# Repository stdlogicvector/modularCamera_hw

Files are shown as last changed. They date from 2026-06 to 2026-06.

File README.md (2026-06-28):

# ModularCamera Hardware

This repository contains the schematics and layouts for the PCBs that make up the ModularCamera system.
They are divided into three categories:

## Interface

USB3 Interface PCB

This is the layer that connects the modularCamera to a PC. At the moment the following interfaces are implemented:

- USB3: Using a Cypress FX3 chip to communicate with a PC via an USB-C cable
- GigE: Providing a Gigabit Ethernet connection with an optional PoE add-on board

The boards are fully self contained, bringing all the power supplies and configuration memories they need.
To connect to the next layer, a 70 pin connector transports up to 42 signals plus 22x GND and 6x 5V.

## Processing

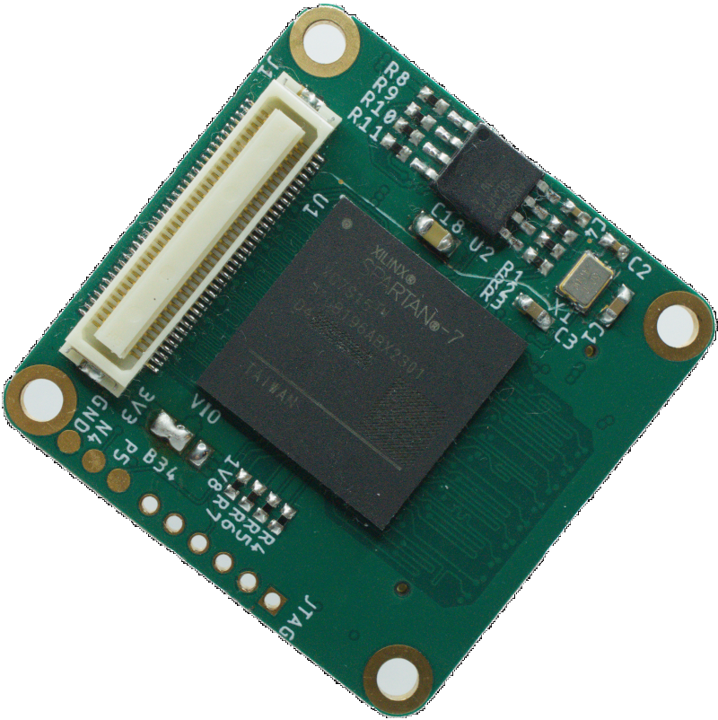
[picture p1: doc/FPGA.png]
Spartan7 Processing PCB


The central layer of the stack does everything from controlling the sensors,  processing the data and formatting it for output. Right now, there are two FPGA boards, but microcontrollers would also be possible.

- Spartan7: A XC72S15 FPGA from Xilinx
- Spartan6: A XC6SLX16 FPGA from Xilinx

Besides the FPGA, the boards have several power supplies for the FPGA, a configuration memory and a clock source. The connector to the next layer has  up to 42 signals plus 22x GND and 6x 5V.

## Sensor

EV76C560 Sensor PCB

This is were the modularity shines. With the high flexibility of the FPGAs, almost all sensors can be interfaced with minimal additional components.
The focus lies on image sensors, but the system isn't limited to processing pixels:

- AISC110C: A small image sensor with a resolution of 80x120 px but a maximum framerate of 40000fps! Configured via SPI.
- ADV7182: An SDTV Video Decoder that accepts lots of analog video formats. Configured via I2C.
- HallArray: An 8x8 array of hall sensors interfaced with an analog matrix. Makes magnetic fields visible.
- MT9P031: A 5MP B/W CMOS image sensor with 14fps. Configured via I2C.
- EV76C560: A 1.3MP B/W CMOS image sensor with global shutter and 60ps. Configured via SPI.
- LinearCCD: A board for interfacing several linear CCD arrays. Provides a driver chip for clocking&control signals, a step-up for power supply and up to 3 12bit 5MSPS ADCs. The sensors are connected via an additional board to accomodate for different pinouts.
- NOIP1SN300: A 1.3MP B/W CMOS image sensor with global shutter and up to 815fps. Configured via SPI.
- IBIS5-B-1300: A 1.3MP B/W CMOS image sensor with global shutter and 27fps. Configured via SPI. (WIP)
- Cameralink: A CameraLink-Base Interface with optional PoCL. Makes the modularCamera into a CameraLink framegrabber. (WIP)
- Microphone Array: A board containing three I2S MEMS microphones. (WIP)

The boards should provide everything necessary to operate the sensor. The connector to the lower layer provides 5V and the control/data interface.

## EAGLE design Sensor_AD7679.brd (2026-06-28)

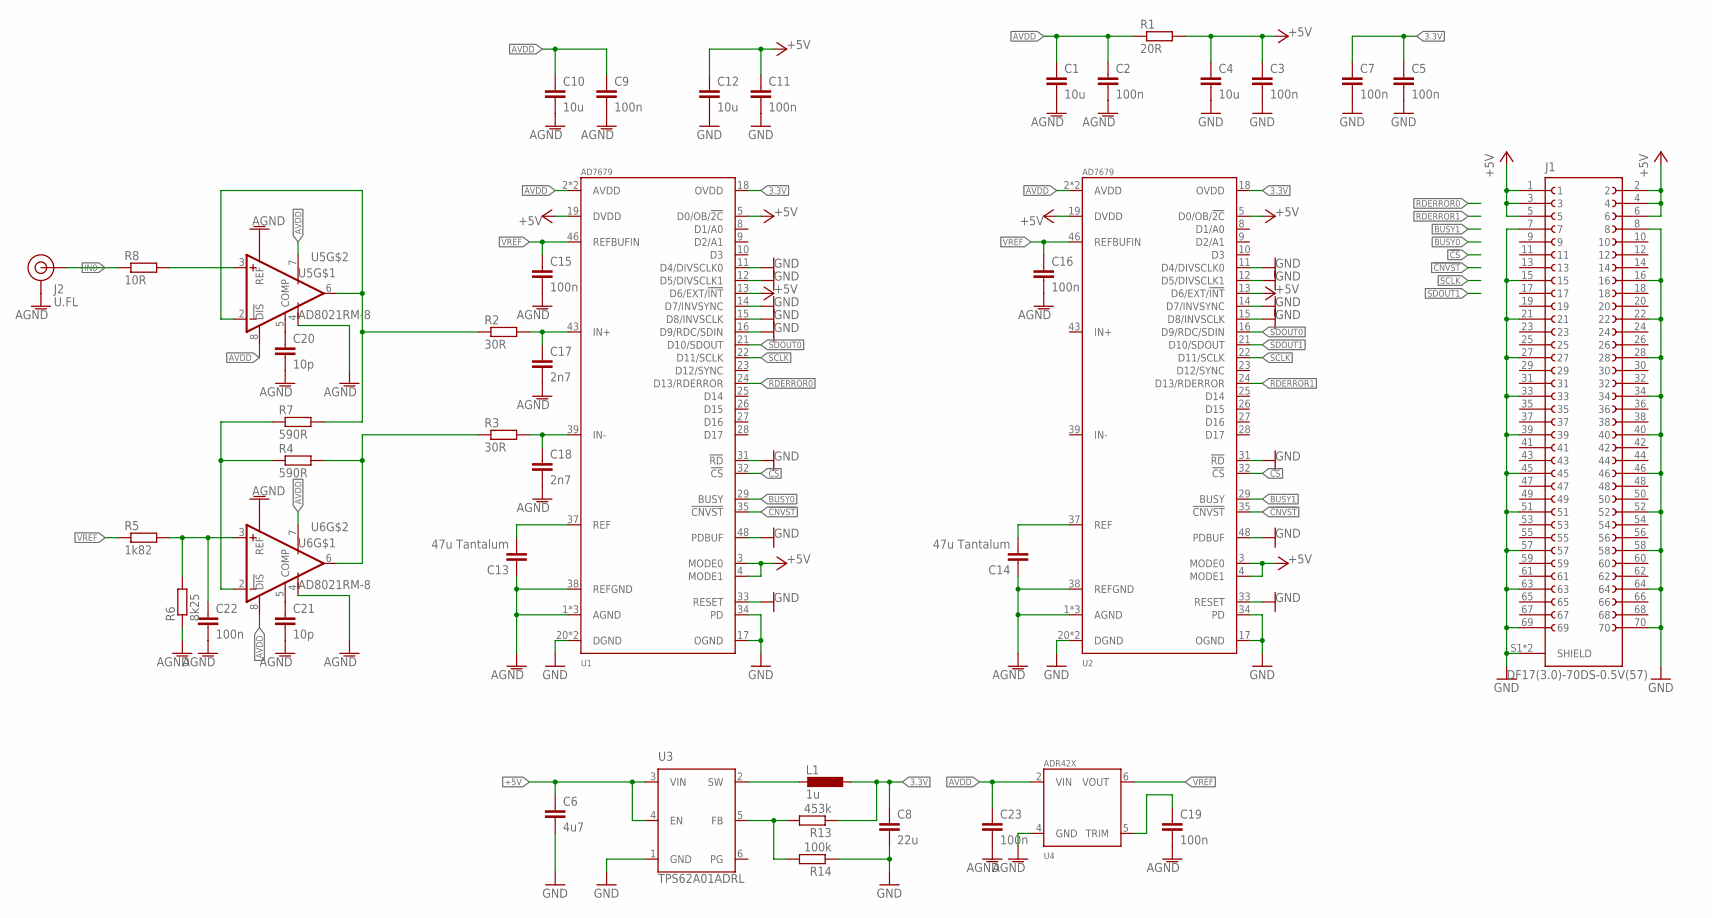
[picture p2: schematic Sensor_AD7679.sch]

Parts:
C1, C4, C10, C12: 10u; C0603
C2, C3, C5, C7, C9, C11, C15, C16, C19, C22, C23: 100n; C0402; LCSC C1525
C6: 4u7; C0603; LCSC C19666
C8: 22u; C0603; LCSC C109448
C13, C14: 47u Tantalum; C1206; DIGIKEY 478-TCA0J476M8R-02CT-ND
C17, C18: 2n7; C0402
C20, C21: 10p; C0402
J1: DF17(3.0)-70DS-0.5V(57)
J2: U.FL; DIGIKEY 26-U.FL-R-SMT-1(01)-ND
L1: 1u; L1008; MPN LQM2HPN1R0MG0L; DIGIKEY 490-5112-1-ND
R1: 20R; R0402
R2, R3: 30R; R0402
R4, R7: 590R; R0402
R5: 1k82; R0402
R6: 8k25; R0402
R8: 10R; R0402
R13: 453k; R0402; LCSC C137978
R14: 100k; R0402; DIGIKEY RMCF0402FT100KCT-ND
U1, U2: AD7679; LQFP48
U3: TPS62A01ADRL; SOTFL50P160X60-6N; DIGIKEY 296-TPS62A01ADRLRCT-ND
U4: ADR42X; MSOP08
U5, U6: AD8021RM-8; MSOP08

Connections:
3.3V: C5.1, C7.1, C8.1, L1.1, R13.1, U1.18 (OVDD), U2.18 (OVDD)
!CNVST: U1.35 (!CNVST), U2.35 (!CNVST)
!CS: U1.32 (!CS), U2.32 (!CS)
+5V: C3.1, C4.1, C6.1, C11.1, C12.1, J1.1, J1.2, J1.3, J1.4, J1.5, J1.6, R1.2, U1.3 (MODE0), U1.4 (MODE1), U1.5 (D0/OB/!2C), U1.19 (DVDD), U2.3 (MODE0), U2.4 (MODE1), U2.5 (D0/OB/!2C), U2.13 (D6/EXT/!INT), U2.19 (DVDD), U3.3 (VIN), U3.4 (EN)
AGND: C1.2, C2.2, C9.2, C10.2, C13.1, C14.1, C15.2, C16.2, C17.2, C18.2, C19.2, C20.2, C21.2, C22.2, C23.2, J2.1 (GND), J2.2 (GND), R6.1, U1.1 (AGND), U1.36 (AGND), U1.38 (REFGND), U1.44 (AGND), U2.1 (AGND), U2.36 (AGND), U2.38 (REFGND), U2.44 (AGND), U4.4 (GND), U5.1 (REF), U5.4 (V-), U6.1 (REF), U6.4 (V-)
AVDD: C1.1, C2.1, C9.1, C10.1, C23.1, R1.1, U1.2 (AVDD), U1.47 (AVDD), U2.2 (AVDD), U2.47 (AVDD), U4.2 (VIN), U5.7 (V+), U5.8 (!DIS), U6.7 (V+), U6.8 (!DIS)
BUSY0: U1.29 (BUSY)
BUSY1: U2.29 (BUSY)
GND: C3.2, C4.2, C5.2, C6.2, C7.2, C8.2, C11.2, C12.2, J1.7, J1.8, J1.15, J1.16, J1.21, J1.22, J1.27, J1.28, J1.33, J1.34, J1.39, J1.40, J1.45, J1.46, J1.51, J1.52, J1.57, J1.58, J1.63, J1.64, J1.69, J1.70, J1.S1 (SHIELD), J1.S2 (SHIELD), R14.1, U1.11 (D4/DIVSCLK0), U1.12 (D5/DIVSCLK1), U1.14 (D7/INVSYNC), U1.17 (OGND), U1.20 (DGND), U1.30 (DGND), U1.31 (!RD), U1.33 (RESET), U1.34 (PD), U1.48 (PDBUF), U2.11 (D4/DIVSCLK0), U2.12 (D5/DIVSCLK1), U2.14 (D7/INVSYNC), U2.15 (D8/INVSCLK), U2.17 (OGND), U2.20 (DGND), U2.30 (DGND), U2.31 (!RD), U2.33 (RESET), U2.34 (PD), U2.48 (PDBUF), U3.1 (GND)
IN0: J2.FEED (SIGNAL), R8.1
unnamed: C13.2, U1.37 (REF)
unnamed: C14.2, U2.37 (REF)
unnamed: U1.15 (D8/INVSCLK), U1.16 (D9/RDC/SDIN)
unnamed: R2.1, R7.2, U5.2 (-IN), U5.6 (OUT)
unnamed: C20.1, U5.5 (COMP)
unnamed: C17.1, R2.2, U1.43 (IN+)
unnamed: C18.1, R3.2, U1.39 (IN-)
unnamed: C19.1, U4.5 (TRIM)
unnamed: R4.1, R7.1, U6.2 (-IN)
unnamed: C21.1, U6.5 (COMP)
unnamed: R3.1, R4.2, U6.6 (OUT)
unnamed: C22.1, R5.2, R6.2, U6.3 (+IN)
unnamed: R8.2, U5.3 (+IN)
unnamed: R13.2, R14.2, U3.5 (FB)
unnamed: L1.2, U3.2 (SW)
RDERROR0: U1.24 (D13/RDERROR)
RDERROR1: U2.24 (D13/RDERROR)
SCLK: U1.22 (D11/SCLK), U2.22 (D11/SCLK)
SDOUT0: U1.21 (D10/SDOUT), U2.16 (D9/RDC/SDIN)
SDOUT1: U2.21 (D10/SDOUT)
VREF: C15.1, C16.1, R5.1, U1.46 (REFBUFIN), U2.46 (REFBUFIN), U4.6 (VOUT)

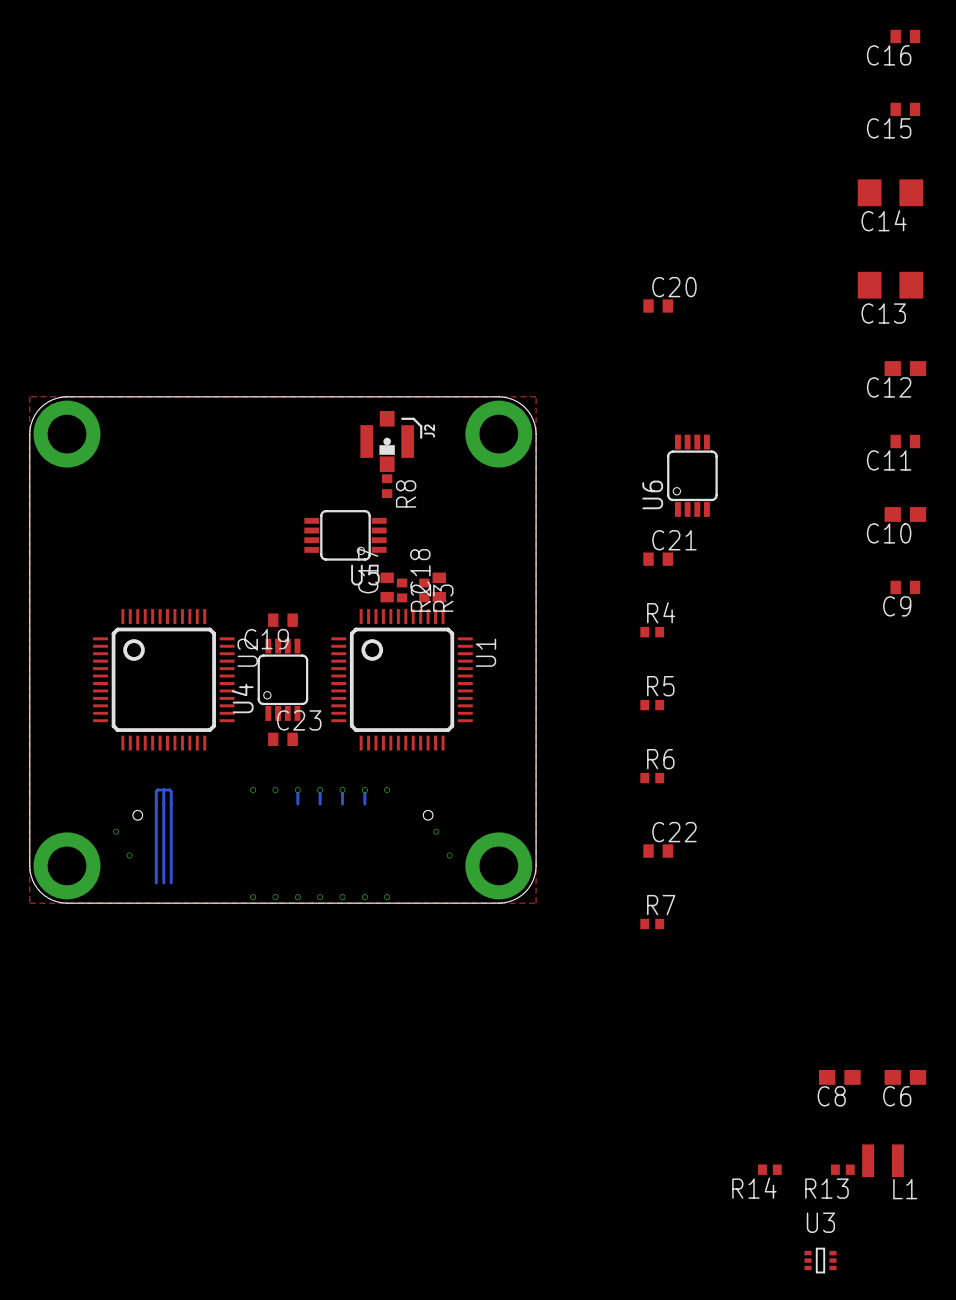
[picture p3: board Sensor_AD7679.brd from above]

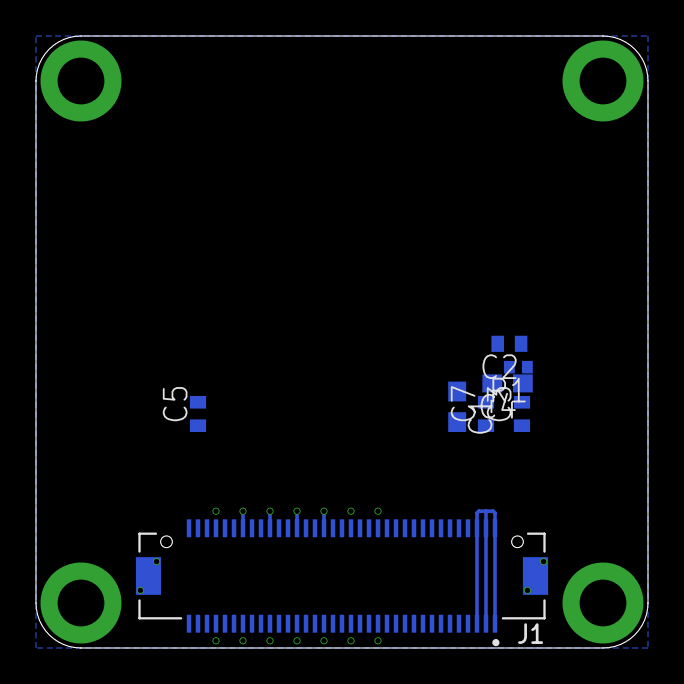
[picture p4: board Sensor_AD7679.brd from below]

Board: 4 copper layers, 34.0 x 34.0 mm, 42 parts (8 on the bottom side), 26 nets.

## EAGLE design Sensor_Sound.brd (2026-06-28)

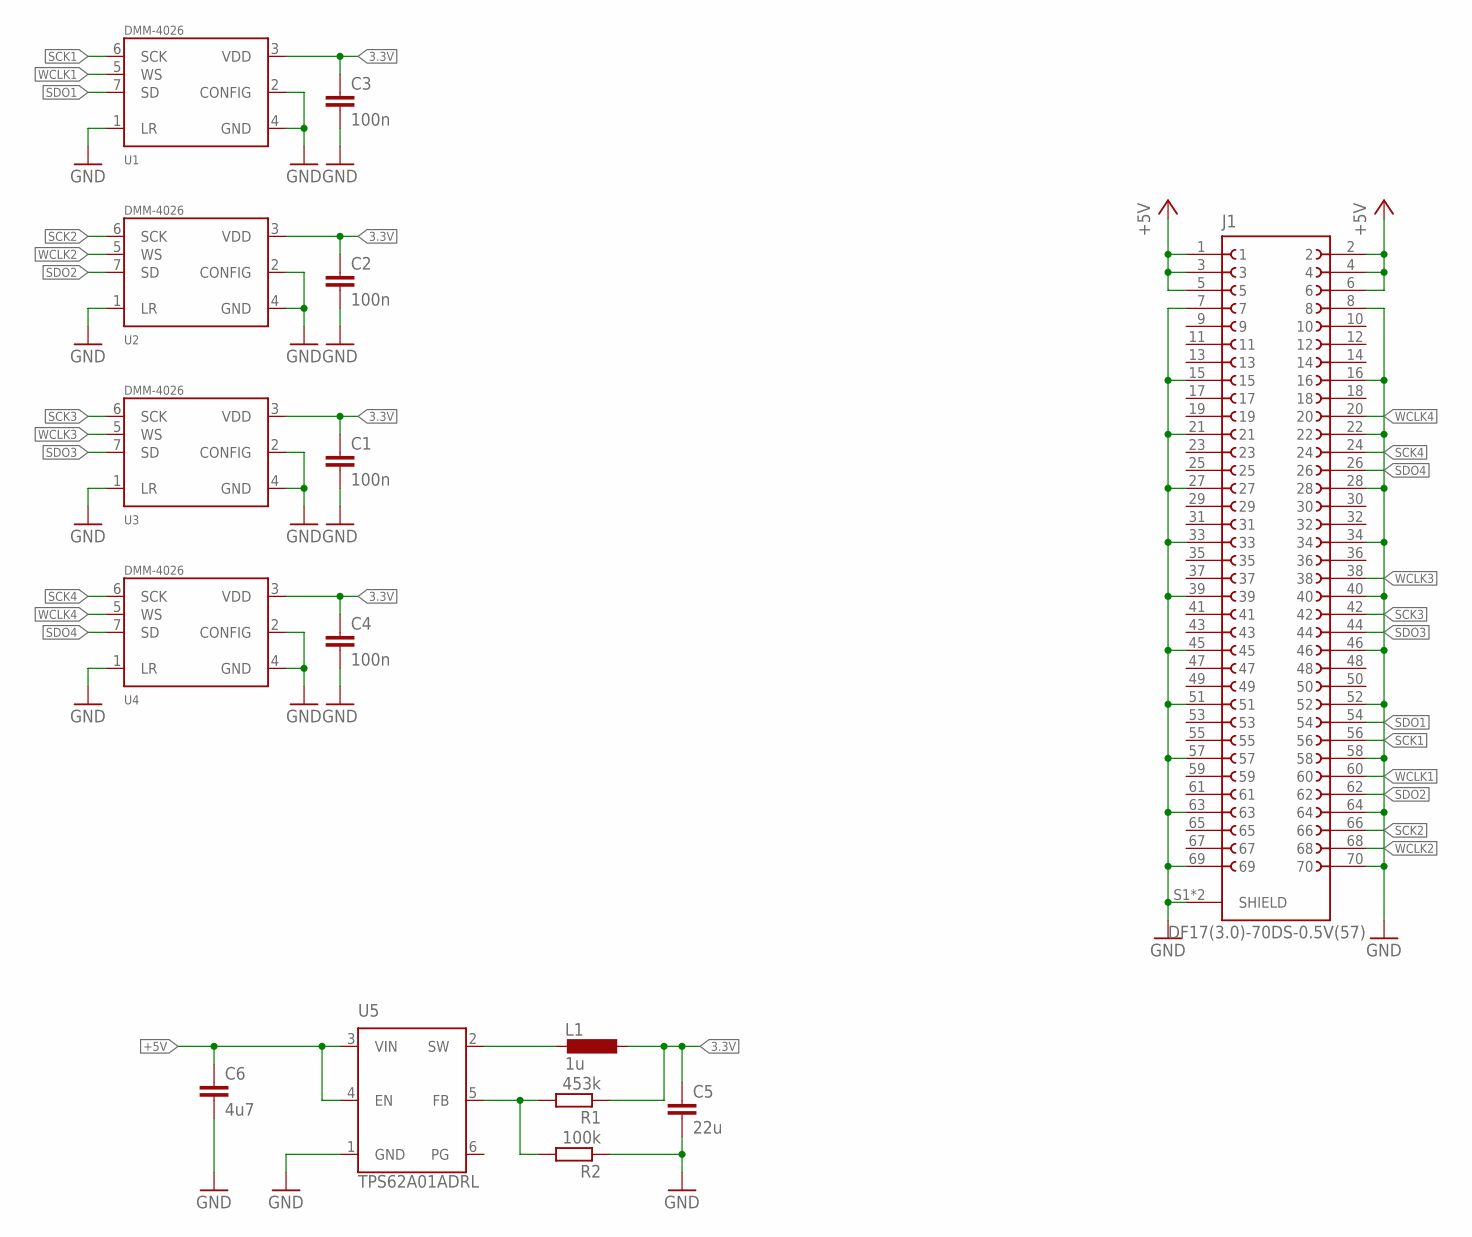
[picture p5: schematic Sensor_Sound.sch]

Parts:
C1, C2, C3, C4: 100n; C0402; LCSC C1525
C5: 22u; C0603; LCSC C109448
C6: 4u7; C0603; LCSC C19666
J1: DF17(3.0)-70DS-0.5V(57)
L1: 1u; L1008; MPN LQM2HPN1R0MG0L; DIGIKEY 490-5112-1-ND
R1: 453k; R0402; LCSC C137978
R2: 100k; R0402; DIGIKEY RMCF0402FT100KCT-ND
U1, U2, U3, U4: DMM-4026
U5: TPS62A01ADRL; SOTFL50P160X60-6N; DIGIKEY 296-TPS62A01ADRLRCT-ND

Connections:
3.3V: C1.1, C2.1, C3.1, C4.1, C5.1, L1.1, R1.1, U1.3 (VDD), U2.3 (VDD), U3.3 (VDD), U4.3 (VDD)
+5V: C6.1, J1.1, J1.2, J1.3, J1.4, J1.5, J1.6, U5.3 (VIN), U5.4 (EN)
GND: C1.2, C2.2, C3.2, C4.2, C5.2, C6.2, J1.7, J1.8, J1.15, J1.16, J1.21, J1.22, J1.27, J1.28, J1.33, J1.34, J1.39, J1.40, J1.45, J1.46, J1.51, J1.52, J1.57, J1.58, J1.63, J1.64, J1.69, J1.70, J1.S1 (SHIELD), J1.S2 (SHIELD), R2.1, U1.1 (LR), U1.2 (CONFIG), U1.4 (GND), U2.1 (LR), U2.2 (CONFIG), U2.4 (GND), U3.1 (LR), U3.2 (CONFIG), U3.4 (GND), U4.1 (LR), U4.2 (CONFIG), U4.4 (GND), U5.1 (GND)
unnamed: R1.2, R2.2, U5.5 (FB)
unnamed: L1.2, U5.2 (SW)
SCK1: J1.56, U1.6 (SCK)
SCK2: J1.66, U2.6 (SCK)
SCK3: J1.42, U3.6 (SCK)
SCK4: J1.24, U4.6 (SCK)
SDO1: J1.54, U1.7 (SD)
SDO2: J1.62, U2.7 (SD)
SDO3: J1.44, U3.7 (SD)
SDO4: J1.26, U4.7 (SD)
WCLK1: J1.60, U1.5 (WS)
WCLK2: J1.68, U2.5 (WS)
WCLK3: J1.38, U3.5 (WS)
WCLK4: J1.20, U4.5 (WS)

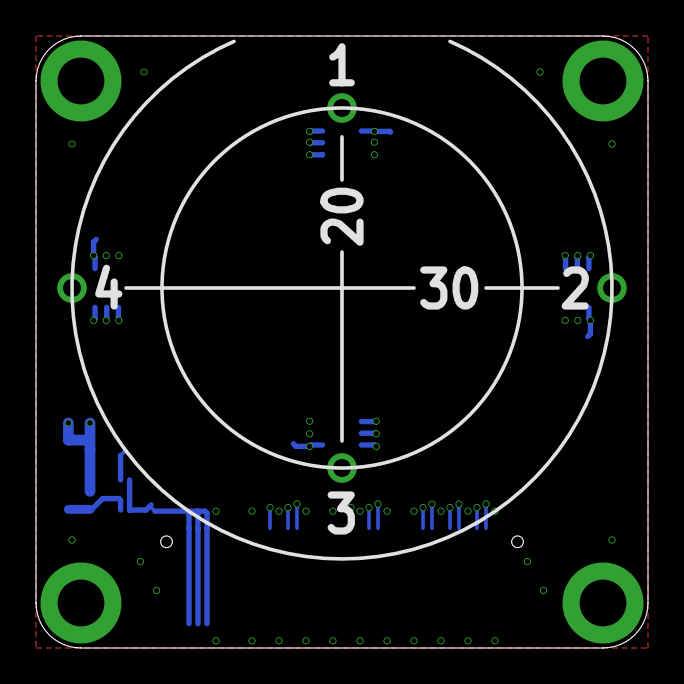
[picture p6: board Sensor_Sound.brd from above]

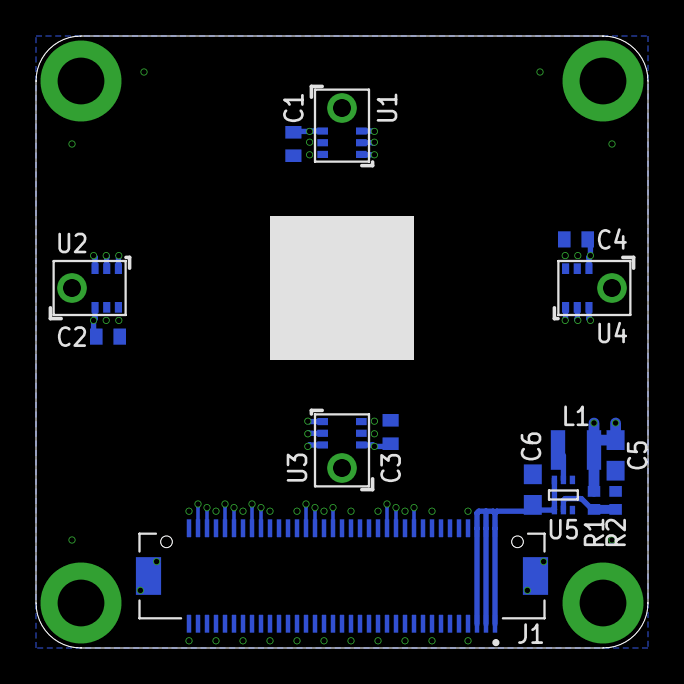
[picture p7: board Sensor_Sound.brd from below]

Board: 4 copper layers, 34.0 x 34.0 mm, 15 parts (15 on the bottom side), 17 nets.

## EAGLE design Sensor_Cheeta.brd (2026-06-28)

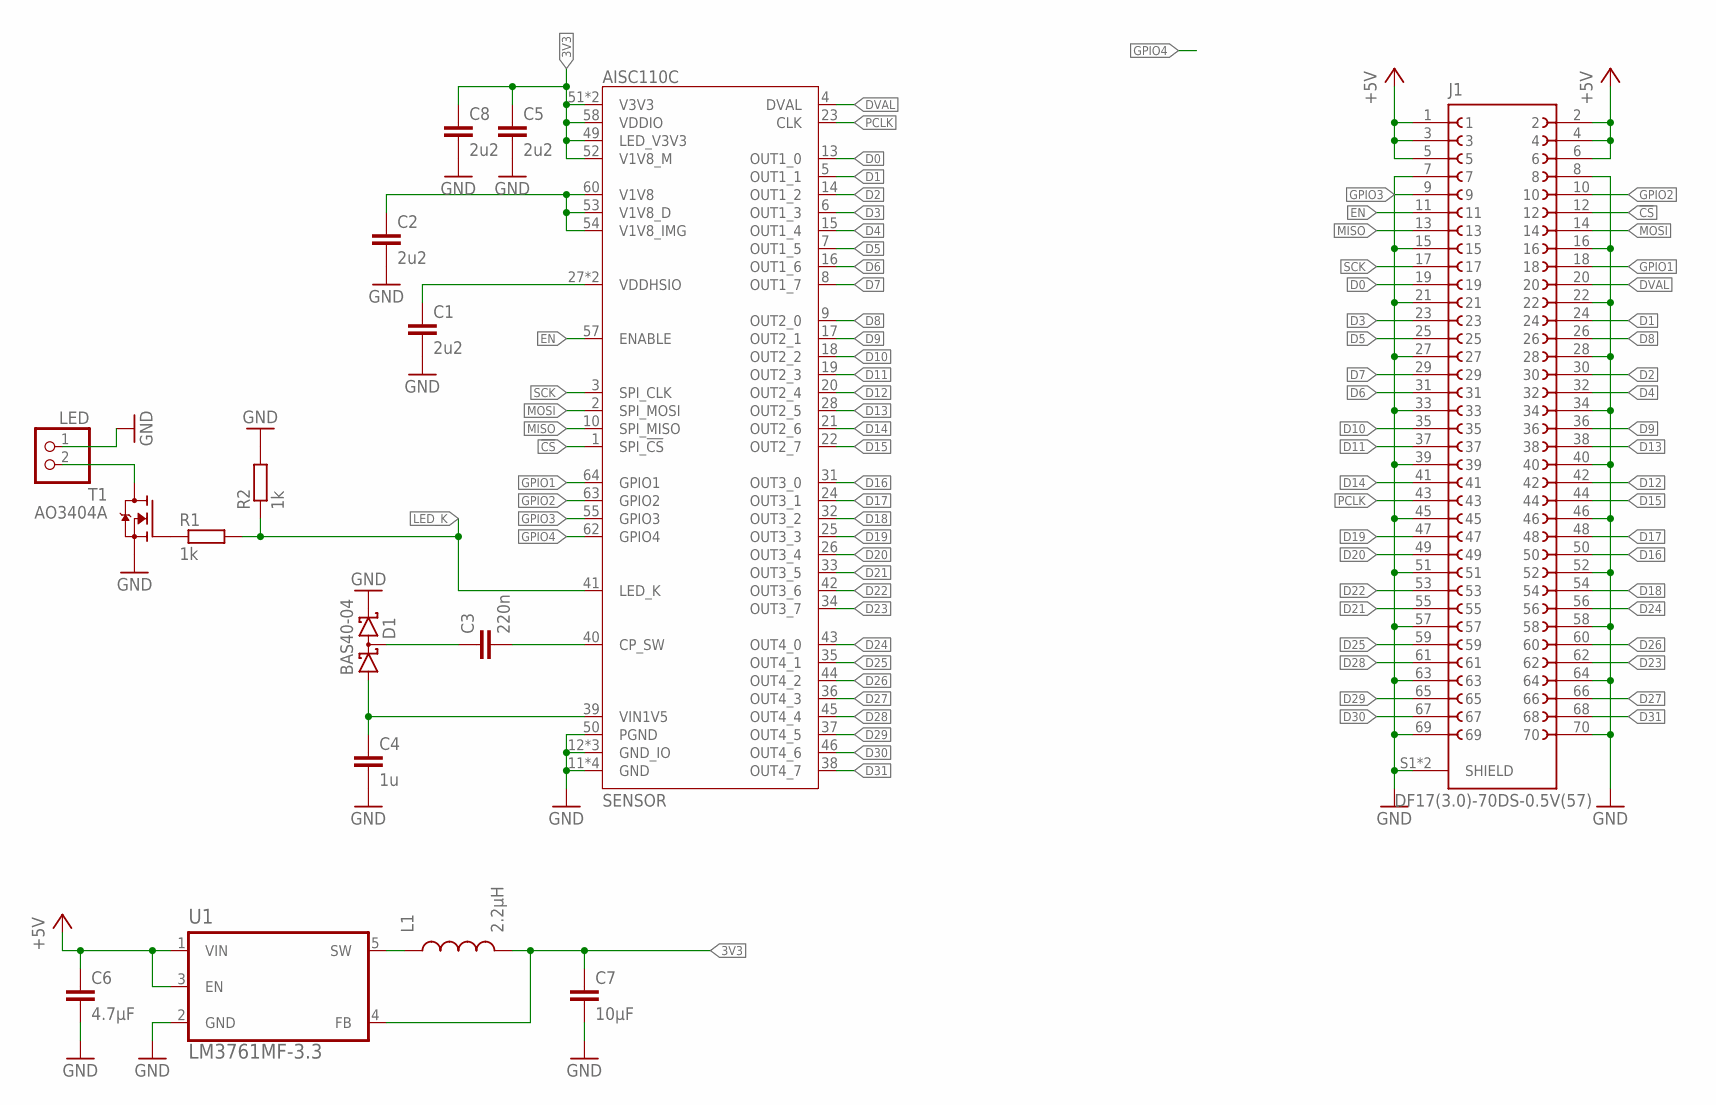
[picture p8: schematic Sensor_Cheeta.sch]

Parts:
C1, C2, C5, C8: 2u2; C0603
C3: 220n; C0603
C4: 1u; C0603
C6: 4.7µF; C0603
C7: 10µF; C0603
D1: BAS40-04; SOT23
J1: DF17(3.0)-70DS-0.5V(57)
L1: 2.2µH; SO3314; FARNELL 2457514
LED: PINHD-1X2; 1X02
R1, R2: 1k; R0603; LCSC C11702
SENSOR: AISC110C; 64_LD_OLGA
T1: AO3404A; SOT23; LCSC C30010
U1: LM3761MF-3.3; SOT95P284X122-5N

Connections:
3V3: C5.1, C7.1, C8.1, L1.2, SENSOR.49 (LED_V3V3), SENSOR.51 (V3V3), SENSOR.52 (V1V8_M), SENSOR.58 (VDDIO), SENSOR.59 (V3V3), U1.4 (FB)
!CS: J1.12, SENSOR.1 (SPI_!CS)
+5V: C6.1, J1.1, J1.2, J1.3, J1.4, J1.5, J1.6, U1.1 (VIN), U1.3 (EN)
D0: J1.19, SENSOR.13 (OUT1_0)
D1: J1.24, SENSOR.5 (OUT1_1)
D2: J1.30, SENSOR.14 (OUT1_2)
D3: J1.23, SENSOR.6 (OUT1_3)
D4: J1.32, SENSOR.15 (OUT1_4)
D5: J1.25, SENSOR.7 (OUT1_5)
D6: J1.31, SENSOR.16 (OUT1_6)
D7: J1.29, SENSOR.8 (OUT1_7)
D8: J1.26, SENSOR.9 (OUT2_0)
D9: J1.36, SENSOR.17 (OUT2_1)
D10: J1.35, SENSOR.18 (OUT2_2)
D11: J1.37, SENSOR.19 (OUT2_3)
D12: J1.42, SENSOR.20 (OUT2_4)
D13: J1.38, SENSOR.28 (OUT2_5)
D14: J1.41, SENSOR.21 (OUT2_6)
D15: J1.44, SENSOR.22 (OUT2_7)
D16: J1.50, SENSOR.31 (OUT3_0)
D17: J1.48, SENSOR.24 (OUT3_1)
D18: J1.54, SENSOR.32 (OUT3_2)
D19: J1.47, SENSOR.25 (OUT3_3)
D20: J1.49, SENSOR.26 (OUT3_4)
D21: J1.55, SENSOR.33 (OUT3_5)
D22: J1.53, SENSOR.42 (OUT3_6)
D23: J1.62, SENSOR.34 (OUT3_7)
D24: J1.56, SENSOR.43 (OUT4_0)
D25: J1.59, SENSOR.35 (OUT4_1)
D26: J1.60, SENSOR.44 (OUT4_2)
D27: J1.66, SENSOR.36 (OUT4_3)
D28: J1.61, SENSOR.45 (OUT4_4)
D29: J1.65, SENSOR.37 (OUT4_5)
D30: J1.67, SENSOR.46 (OUT4_6)
D31: J1.68, SENSOR.38 (OUT4_7)
DVAL: J1.20, SENSOR.4 (DVAL)
EN: J1.11, SENSOR.57 (ENABLE)
GND: C1.2, C2.2, C4.2, C5.2, C6.2, C7.2, C8.2, D1.2 (C2), J1.7, J1.8, J1.15, J1.16, J1.21, J1.22, J1.27, J1.28, J1.33, J1.34, J1.39, J1.40, J1.45, J1.46, J1.51, J1.52, J1.57, J1.58, J1.63, J1.64, J1.69, J1.70, J1.S1 (SHIELD), J1.S2 (SHIELD), LED.1, R2.2, SENSOR.11 (GND), SENSOR.12 (GND_IO), SENSOR.30 (GND_IO), SENSOR.47 (GND_IO), SENSOR.48 (GND), SENSOR.50 (PGND), SENSOR.56 (GND), SENSOR.61 (GND), T1.2 (S), U1.2 (GND)
GPIO1: J1.18, SENSOR.64 (GPIO1)
GPIO2: J1.10, SENSOR.63 (GPIO2)
GPIO3: J1.9, SENSOR.55 (GPIO3)
GPIO4: SENSOR.62 (GPIO4)
LED_K: R1.2, R2.1, SENSOR.41 (LED_K)
MISO: J1.13, SENSOR.10 (SPI_MISO)
MOSI: J1.14, SENSOR.2 (SPI_MOSI)
unnamed: C3.2, SENSOR.40 (CP_SW)
unnamed: C4.1, D1.1 (A1), SENSOR.39 (VIN1V5)
unnamed: C3.1, D1.3 (C1A2)
unnamed: LED.2, T1.3 (D)
unnamed: L1.1, U1.5 (SW)
unnamed: C2.1, SENSOR.53 (V1V8_D), SENSOR.54 (V1V8_IMG), SENSOR.60 (V1V8)
unnamed: C1.1, SENSOR.27 (VDDHSIO), SENSOR.29 (VDDHSIO)
unnamed: R1.1, T1.1 (G)
PCLK: J1.43, SENSOR.23 (CLK)
SCK: J1.17, SENSOR.3 (SPI_CLK)

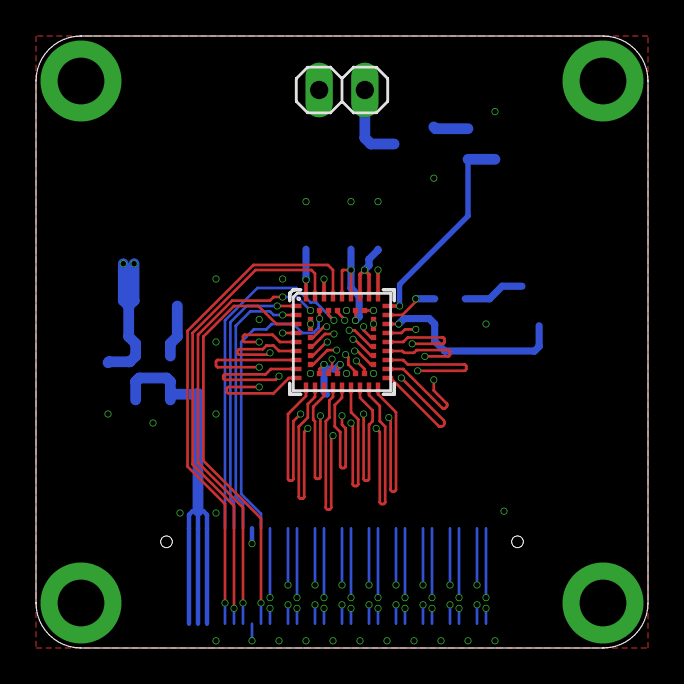
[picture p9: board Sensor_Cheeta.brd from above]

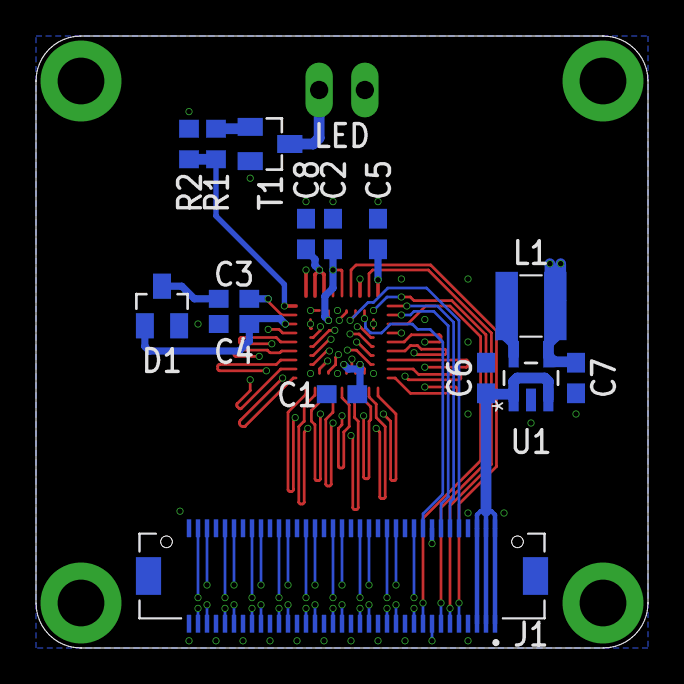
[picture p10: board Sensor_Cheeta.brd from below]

Board: 4 copper layers, 34.0 x 34.0 mm, 17 parts (15 on the bottom side), 54 nets.

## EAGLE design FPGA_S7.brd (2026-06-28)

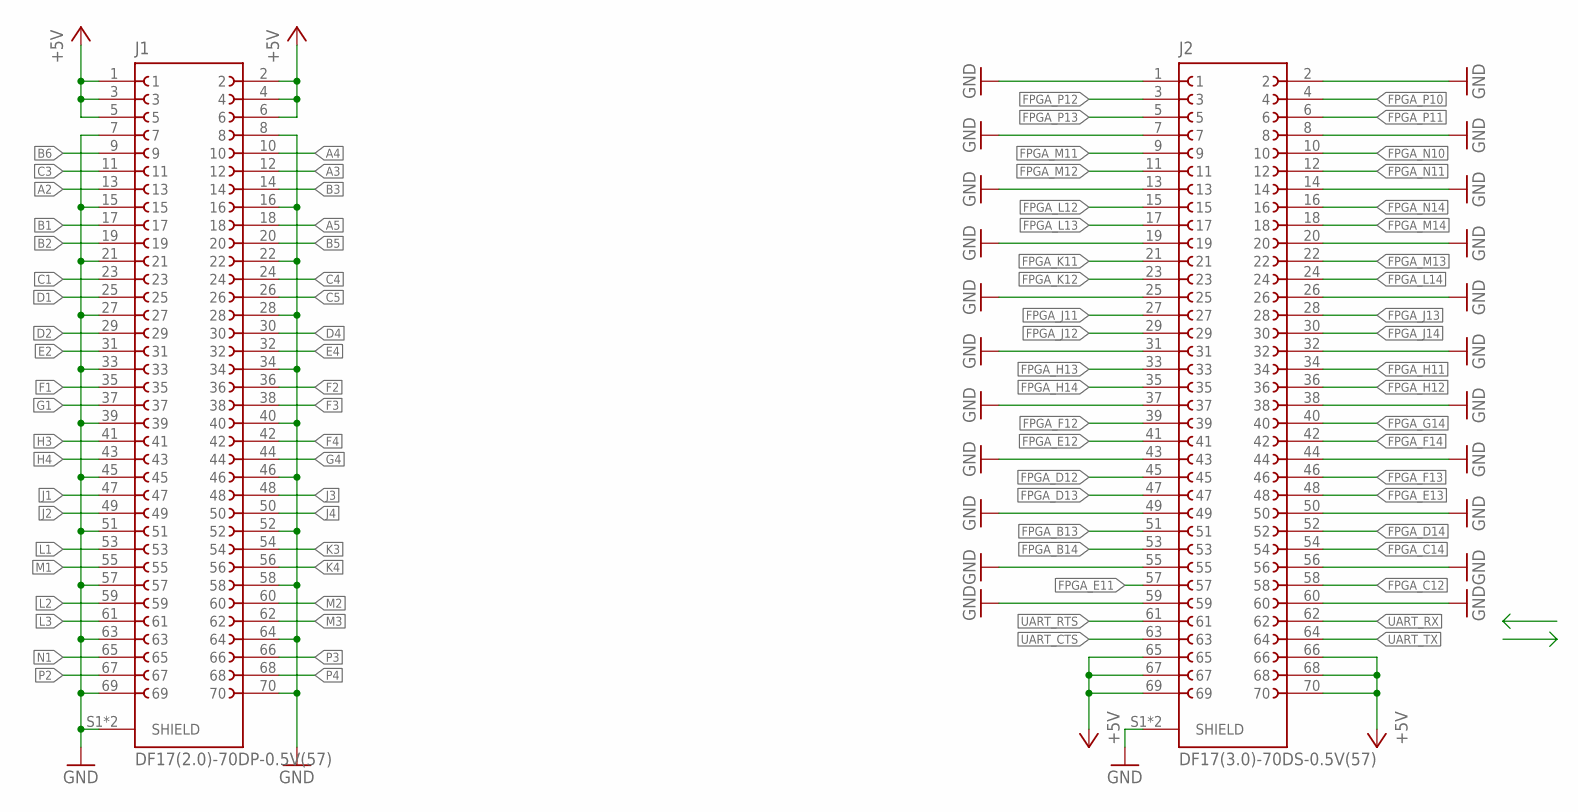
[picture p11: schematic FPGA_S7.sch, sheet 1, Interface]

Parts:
J1: DF17(2.0)-70DP-0.5V(57); DIGIKEY H11133CT-ND
J2: DF17(3.0)-70DS-0.5V(57); DIGIKEY H11112CT-ND

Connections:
+5V: J1.1, J1.2, J1.3, J1.4, J1.5, J1.6, J2.65, J2.66, J2.67, J2.68, J2.69, J2.70; also elsewhere on the board
A2: J1.13; also elsewhere on the board
A3: J1.12; also elsewhere on the board
A4: J1.10; also elsewhere on the board
A5: J1.18; also elsewhere on the board
B1: J1.17; also elsewhere on the board
B2: J1.19; also elsewhere on the board
B3: J1.14; also elsewhere on the board
B5: J1.20; also elsewhere on the board
B6: J1.9; also elsewhere on the board
C1: J1.23; also elsewhere on the board
C3: J1.11; also elsewhere on the board
C4: J1.24; also elsewhere on the board
C5: J1.26; also elsewhere on the board
D1: J1.25; also elsewhere on the board
D2: J1.29; also elsewhere on the board
D4: J1.30; also elsewhere on the board
E2: J1.31; also elsewhere on the board
E4: J1.32; also elsewhere on the board
F1: J1.35; also elsewhere on the board
F2: J1.36; also elsewhere on the board
F3: J1.38; also elsewhere on the board
F4: J1.42; also elsewhere on the board
FPGA_B13: J2.51; also elsewhere on the board
FPGA_B14: J2.53; also elsewhere on the board
FPGA_C12: J2.58; also elsewhere on the board
FPGA_C14: J2.54; also elsewhere on the board
FPGA_D12: J2.45; also elsewhere on the board
FPGA_D13: J2.47; also elsewhere on the board
FPGA_D14: J2.52; also elsewhere on the board
FPGA_E11: J2.57; also elsewhere on the board
FPGA_E12: J2.41; also elsewhere on the board
FPGA_E13: J2.48; also elsewhere on the board
FPGA_F12: J2.39; also elsewhere on the board
FPGA_F13: J2.46; also elsewhere on the board
FPGA_F14: J2.42; also elsewhere on the board
FPGA_G14: J2.40; also elsewhere on the board
FPGA_H11: J2.34; also elsewhere on the board
FPGA_H12: J2.36; also elsewhere on the board
FPGA_H13: J2.33; also elsewhere on the board
FPGA_H14: J2.35; also elsewhere on the board
FPGA_J11: J2.27; also elsewhere on the board
FPGA_J12: J2.29; also elsewhere on the board
FPGA_J13: J2.28; also elsewhere on the board
FPGA_J14: J2.30; also elsewhere on the board
FPGA_K11: J2.21; also elsewhere on the board
FPGA_K12: J2.23; also elsewhere on the board
FPGA_L12: J2.15; also elsewhere on the board
FPGA_L13: J2.17; also elsewhere on the board
FPGA_L14: J2.24; also elsewhere on the board
FPGA_M11: J2.9; also elsewhere on the board
FPGA_M12: J2.11; also elsewhere on the board
FPGA_M13: J2.22; also elsewhere on the board
FPGA_M14: J2.18; also elsewhere on the board
FPGA_N10: J2.10; also elsewhere on the board
FPGA_N11: J2.12; also elsewhere on the board
FPGA_N14: J2.16; also elsewhere on the board
FPGA_P10: J2.4; also elsewhere on the board
FPGA_P11: J2.6; also elsewhere on the board
FPGA_P12: J2.3; also elsewhere on the board
FPGA_P13: J2.5; also elsewhere on the board
G1: J1.37; also elsewhere on the board
G4: J1.44; also elsewhere on the board
GND: J1.7, J1.8, J1.15, J1.16, J1.21, J1.22, J1.27, J1.28, J1.33, J1.34, J1.39, J1.40, J1.45, J1.46, J1.51, J1.52, J1.57, J1.58, J1.63, J1.64, J1.69, J1.70, J1.S1 (SHIELD), J1.S2 (SHIELD), J2.1, J2.2, J2.7, J2.8, J2.13, J2.14, J2.19, J2.20, J2.25, J2.26, J2.31, J2.32, J2.37, J2.38, J2.43, J2.44, J2.49, J2.50, J2.55, J2.56, J2.59, J2.60, J2.S1 (SHIELD), J2.S2 (SHIELD); also elsewhere on the board
H3: J1.41; also elsewhere on the board
H4: J1.43; also elsewhere on the board
J1: J1.47; also elsewhere on the board
J2: J1.49; also elsewhere on the board
J3: J1.48; also elsewhere on the board
J4: J1.50; also elsewhere on the board
K3: J1.54; also elsewhere on the board
K4: J1.56; also elsewhere on the board
L1: J1.53; also elsewhere on the board
L2: J1.59; also elsewhere on the board
L3: J1.61; also elsewhere on the board
M1: J1.55; also elsewhere on the board
M2: J1.60; also elsewhere on the board
M3: J1.62; also elsewhere on the board
N1: J1.65; also elsewhere on the board
P2: J1.67; also elsewhere on the board
P3: J1.66; also elsewhere on the board
P4: J1.68; also elsewhere on the board
UART_CTS: J2.63; also elsewhere on the board
UART_RTS: J2.61; also elsewhere on the board
UART_RX: J2.62; also elsewhere on the board
UART_TX: J2.64; also elsewhere on the board

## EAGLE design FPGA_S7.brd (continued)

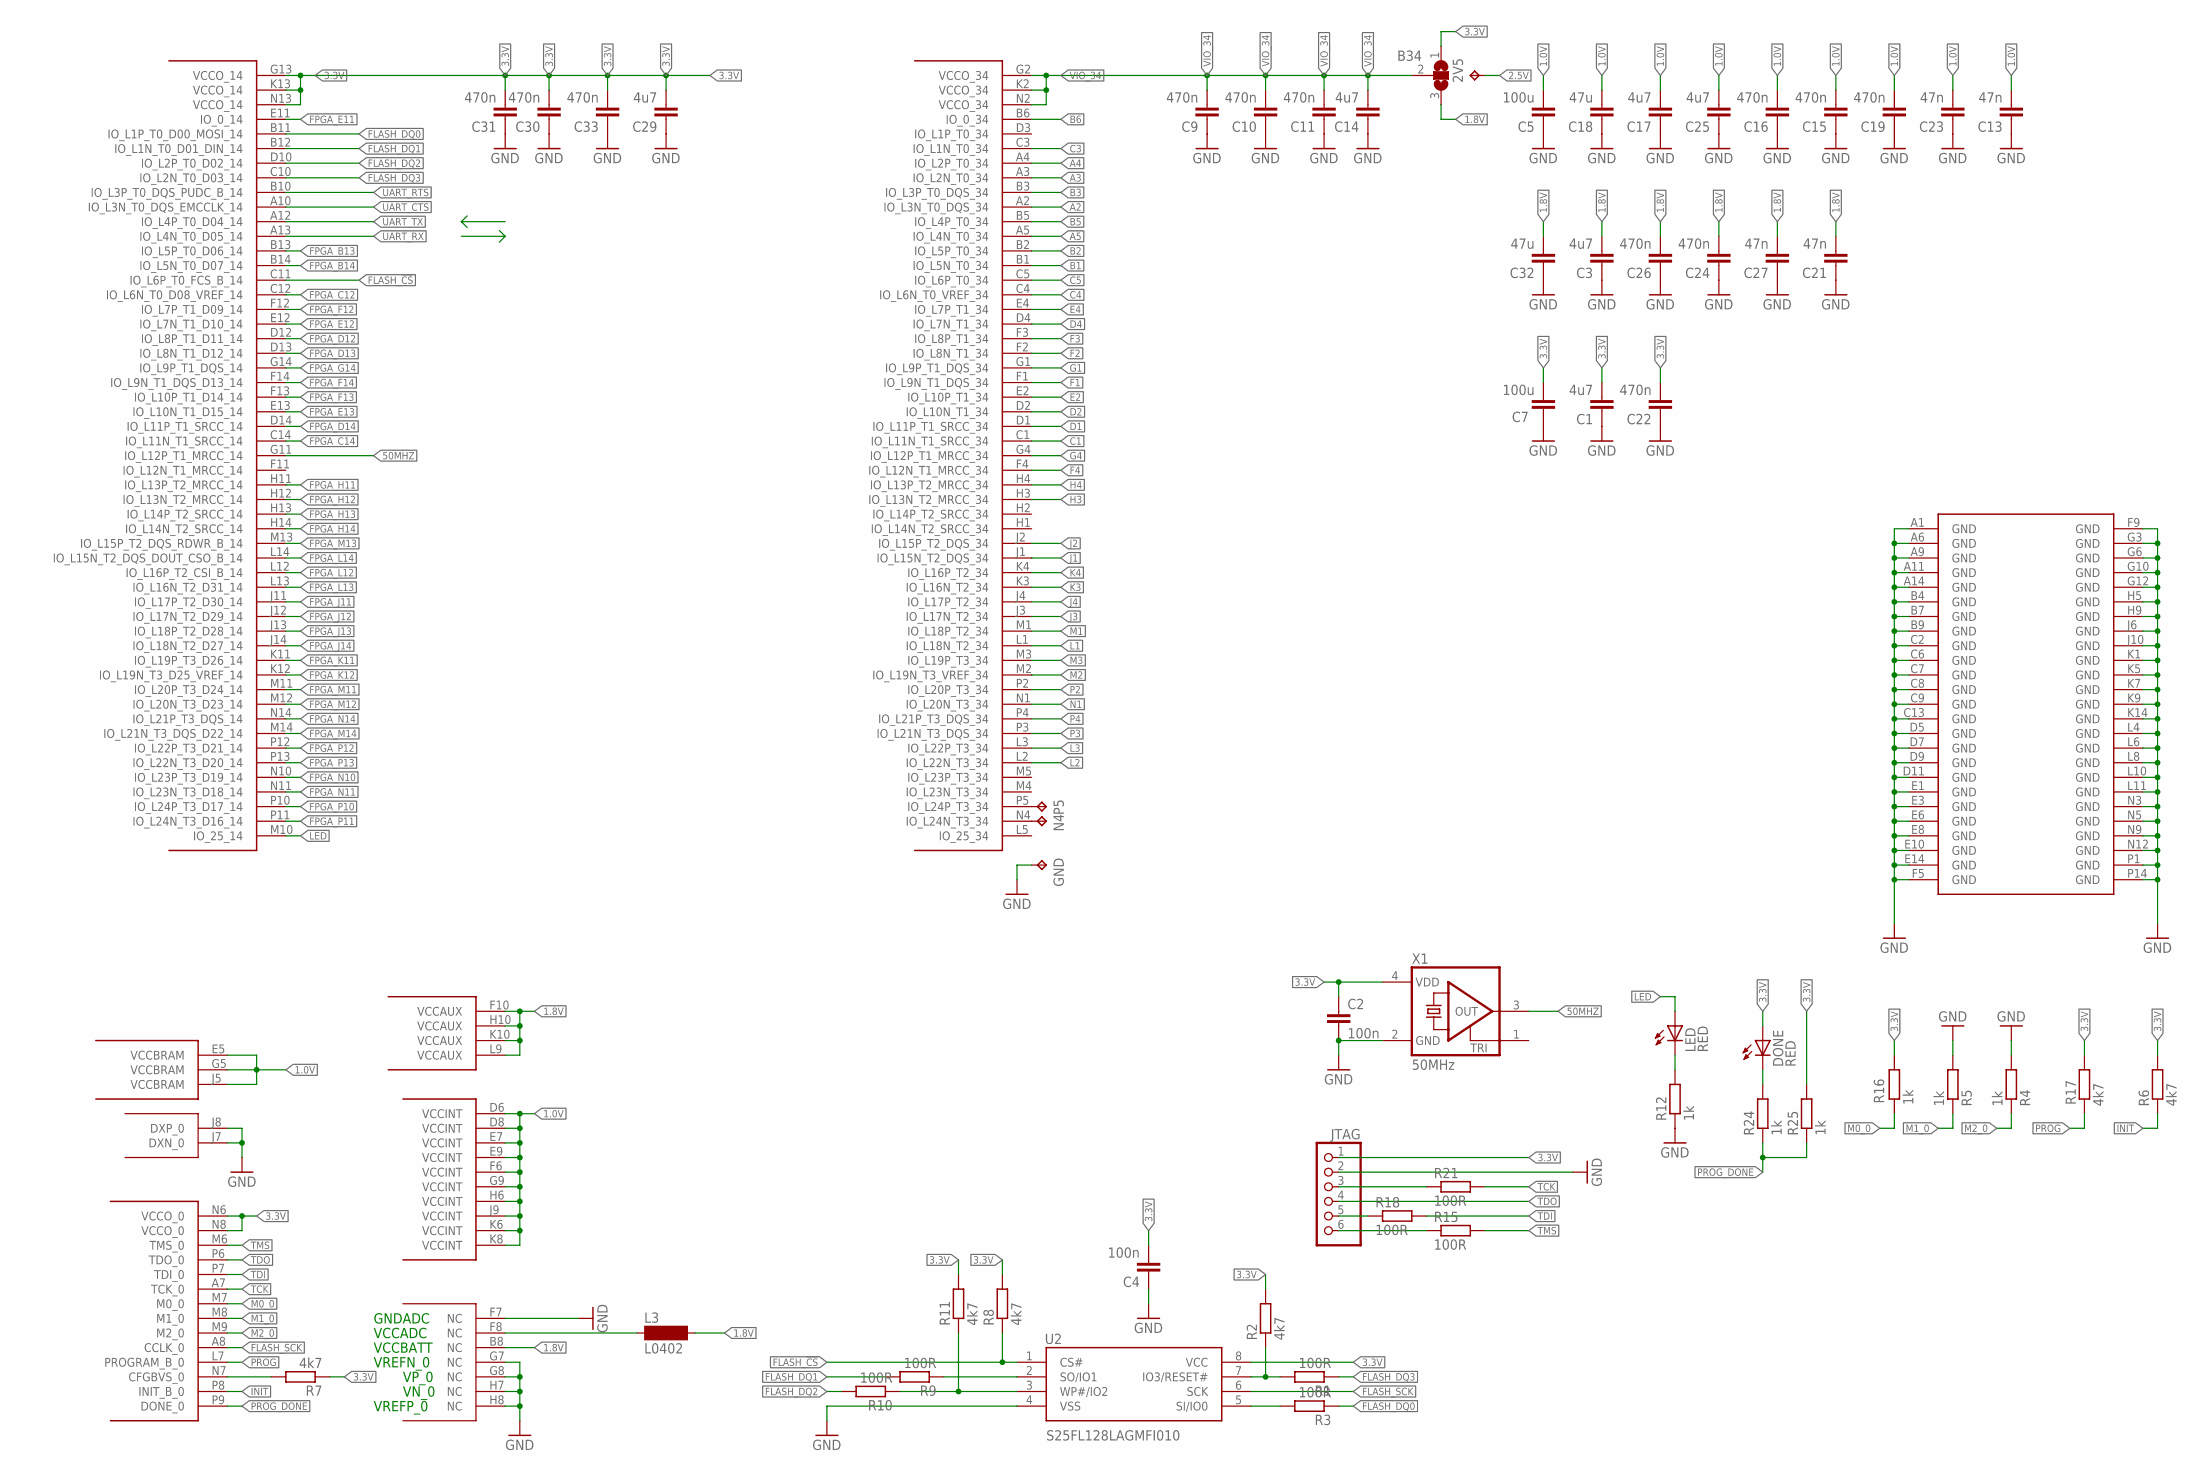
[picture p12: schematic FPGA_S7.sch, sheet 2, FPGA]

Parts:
2V5: TPTP12SQ; TP12SQ
B34: SJ2W; SJ_2
C1, C3, C14, C17, C25, C29: 4u7; C0603; LCSC C19666
C2, C4: 100n; C0402; LCSC C1525
C5, C7: 100u; C1206; DIGIKEY 490-GRM31CD80J107MEA8LCT-ND
C9, C10, C11, C15, C16, C19, C22, C24, C26, C30, C31, C33: 470n; C0402; LCSC C162159
C13, C21, C23, C27: 47n; C0402; LCSC C327054
C18, C32: 47u; C0805; LCSC C77072
DONE: RED; CHIP-LED0603; LCSC C7493803
GND: TPTP15R; TP15R
JTAG: PINHD-1X6_2.00; 1X06M
L3: L0402; C0402; LCSC C88970
LED: RED; CHIP-LED0603; LCSC C7493803
N4: TPTP15R; TP15R
P5: TPTP15R; TP15R
R1, R3, R9, R10, R15, R18, R21: 100R; R0402; LCSC C25076
R2, R6, R7, R8, R11, R17: 4k7; R0402; LCSC C25900
R4: 1k; R0402; LCSC C106235
R5, R12, R16, R24, R25: 1k; R0402; LCSC C11702
U1: XC7S15-2FTGB196I; BGA196C100P14X14_1500X1500X155; DIGIKEY 122-2233-ND
U2: S25FL128LAGMFI010; SOIC127P800X216-8N; MPN S25FL128LAGMFI010; DIGIKEY 448-S25FL128LAGMFI010-ND
X1: 50MHz; ASE; MPN_ ASE-50.000MHZ-E-T; FARNELL 2467898

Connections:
1.0V: C5.1, C13.2, C15.2, C16.2, C17.2, C18.1, C19.2, C23.2, C25.2, U1.D6 (VCCINT), U1.D8 (VCCINT), U1.E5 (VCCBRAM), U1.E7 (VCCINT), U1.E9 (VCCINT), U1.F6 (VCCINT), U1.G5 (VCCBRAM), U1.G9 (VCCINT), U1.H6 (VCCINT), U1.J5 (VCCBRAM), U1.J9 (VCCINT), U1.K6 (VCCINT), U1.K8 (VCCINT); also elsewhere on the board
1.8V: B34.3, C3.2, C21.2, C24.2, C26.2, C27.2, C32.2, L3.2, U1.B8 (NC), U1.F10 (VCCAUX), U1.H10 (VCCAUX), U1.K10 (VCCAUX), U1.L9 (VCCAUX); also elsewhere on the board
2.5V: 2V5.TP; also elsewhere on the board
3.3V: B34.1, C1.2, C2.1, C4.2, C7.1, C22.2, C29.2, C30.2, C31.2, C33.2, DONE.A, JTAG.1, R2.2, R6.2, R7.1, R8.2, R11.2, R16.1, R17.1, R25.2, U1.G13 (VCCO_14), U1.K13 (VCCO_14), U1.N6 (VCCO_0), U1.N8 (VCCO_0), U1.N13 (VCCO_14), U2.8 (VCC), X1.4 (VDD); also elsewhere on the board
50MHZ: U1.G11 (IO_L12P_T1_MRCC_14), X1.3 (OUT)
A2: U1.A2 (IO_L3N_T0_DQS_34); also elsewhere on the board
A3: U1.A3 (IO_L2N_T0_34); also elsewhere on the board
A4: U1.A4 (IO_L2P_T0_34); also elsewhere on the board
A5: U1.A5 (IO_L4N_T0_34); also elsewhere on the board
B1: U1.B1 (IO_L5N_T0_34); also elsewhere on the board
B2: U1.B2 (IO_L5P_T0_34); also elsewhere on the board
B3: U1.B3 (IO_L3P_T0_DQS_34); also elsewhere on the board
B5: U1.B5 (IO_L4P_T0_34); also elsewhere on the board
B6: U1.B6 (IO_0_34); also elsewhere on the board
C1: U1.C1 (IO_L11N_T1_SRCC_34); also elsewhere on the board
C3: U1.C3 (IO_L1N_T0_34); also elsewhere on the board
C4: U1.C4 (IO_L6N_T0_VREF_34); also elsewhere on the board
C5: U1.C5 (IO_L6P_T0_34); also elsewhere on the board
D1: U1.D1 (IO_L11P_T1_SRCC_34); also elsewhere on the board
D2: U1.D2 (IO_L10N_T1_34); also elsewhere on the board
D4: U1.D4 (IO_L7N_T1_34); also elsewhere on the board
E2: U1.E2 (IO_L10P_T1_34); also elsewhere on the board
E4: U1.E4 (IO_L7P_T1_34); also elsewhere on the board
F1: U1.F1 (IO_L9N_T1_DQS_34); also elsewhere on the board
F2: U1.F2 (IO_L8N_T1_34); also elsewhere on the board
F3: U1.F3 (IO_L8P_T1_34); also elsewhere on the board
F4: U1.F4 (IO_L12N_T1_MRCC_34); also elsewhere on the board
FLASH_!CS: R8.1, U1.C11 (IO_L6P_T0_FCS_B_14), U2.1 (CS#)
FLASH_DQ0: R3.1, U1.B11 (IO_L1P_T0_D00_MOSI_14)
FLASH_DQ1: R9.2, U1.B12 (IO_L1N_T0_D01_DIN_14)
FLASH_DQ2: R10.2, U1.D10 (IO_L2P_T0_D02_14)
FLASH_DQ3: R1.1, U1.C10 (IO_L2N_T0_D03_14)
FLASH_SCK: U1.A8 (CCLK_0), U2.6 (SCK)
FPGA_B13: U1.B13 (IO_L5P_T0_D06_14); also elsewhere on the board
FPGA_B14: U1.B14 (IO_L5N_T0_D07_14); also elsewhere on the board
FPGA_C12: U1.C12 (IO_L6N_T0_D08_VREF_14); also elsewhere on the board
FPGA_C14: U1.C14 (IO_L11N_T1_SRCC_14); also elsewhere on the board
FPGA_D12: U1.D12 (IO_L8P_T1_D11_14); also elsewhere on the board
FPGA_D13: U1.D13 (IO_L8N_T1_D12_14); also elsewhere on the board
FPGA_D14: U1.D14 (IO_L11P_T1_SRCC_14); also elsewhere on the board
FPGA_E11: U1.E11 (IO_0_14); also elsewhere on the board
FPGA_E12: U1.E12 (IO_L7N_T1_D10_14); also elsewhere on the board
FPGA_E13: U1.E13 (IO_L10N_T1_D15_14); also elsewhere on the board
FPGA_F12: U1.F12 (IO_L7P_T1_D09_14); also elsewhere on the board
FPGA_F13: U1.F13 (IO_L10P_T1_D14_14); also elsewhere on the board
FPGA_F14: U1.F14 (IO_L9N_T1_DQS_D13_14); also elsewhere on the board
FPGA_G14: U1.G14 (IO_L9P_T1_DQS_14); also elsewhere on the board
FPGA_H11: U1.H11 (IO_L13P_T2_MRCC_14); also elsewhere on the board
FPGA_H12: U1.H12 (IO_L13N_T2_MRCC_14); also elsewhere on the board
FPGA_H13: U1.H13 (IO_L14P_T2_SRCC_14); also elsewhere on the board
FPGA_H14: U1.H14 (IO_L14N_T2_SRCC_14); also elsewhere on the board
FPGA_J11: U1.J11 (IO_L17P_T2_D30_14); also elsewhere on the board
FPGA_J12: U1.J12 (IO_L17N_T2_D29_14); also elsewhere on the board
FPGA_J13: U1.J13 (IO_L18P_T2_D28_14); also elsewhere on the board
FPGA_J14: U1.J14 (IO_L18N_T2_D27_14); also elsewhere on the board
FPGA_K11: U1.K11 (IO_L19P_T3_D26_14); also elsewhere on the board
FPGA_K12: U1.K12 (IO_L19N_T3_D25_VREF_14); also elsewhere on the board
FPGA_L12: U1.L12 (IO_L16P_T2_CSI_B_14); also elsewhere on the board
FPGA_L13: U1.L13 (IO_L16N_T2_D31_14); also elsewhere on the board
FPGA_L14: U1.L14 (IO_L15N_T2_DQS_DOUT_CSO_B_14); also elsewhere on the board
FPGA_M11: U1.M11 (IO_L20P_T3_D24_14); also elsewhere on the board
FPGA_M12: U1.M12 (IO_L20N_T3_D23_14); also elsewhere on the board
FPGA_M13: U1.M13 (IO_L15P_T2_DQS_RDWR_B_14); also elsewhere on the board
FPGA_M14: U1.M14 (IO_L21N_T3_DQS_D22_14); also elsewhere on the board
FPGA_N10: U1.N10 (IO_L23P_T3_D19_14); also elsewhere on the board
FPGA_N11: U1.N11 (IO_L23N_T3_D18_14); also elsewhere on the board
FPGA_N14: U1.N14 (IO_L21P_T3_DQS_14); also elsewhere on the board
FPGA_P10: U1.P10 (IO_L24P_T3_D17_14); also elsewhere on the board
FPGA_P11: U1.P11 (IO_L24N_T3_D16_14); also elsewhere on the board
FPGA_P12: U1.P12 (IO_L22P_T3_D21_14); also elsewhere on the board
FPGA_P13: U1.P13 (IO_L22N_T3_D20_14); also elsewhere on the board
G1: U1.G1 (IO_L9P_T1_DQS_34); also elsewhere on the board
G4: U1.G4 (IO_L12P_T1_MRCC_34); also elsewhere on the board
GND: C1.1, C2.2, C3.1, C4.1, C5.2, C7.2, C9.1, C10.1, C11.1, C13.1, C14.1, C15.1, C16.1, C17.1, C18.2, C19.1, C21.1, C22.1, C23.1, C24.1, C25.1, C26.1, C27.1, C29.1, C30.1, C31.1, C32.1, C33.1, GND.TP, JTAG.2, R4.2, R5.2, R12.1, U1.A1 (GND), U1.A6 (GND), U1.A9 (GND), U1.A11 (GND), U1.A14 (GND), U1.B4 (GND), U1.B7 (GND), U1.B9 (GND), U1.C2 (GND), U1.C6 (GND), U1.C7 (GND), U1.C8 (GND), U1.C9 (GND), U1.C13 (GND), U1.D5 (GND), U1.D7 (GND), U1.D9 (GND), U1.D11 (GND), U1.E1 (GND), U1.E3 (GND), U1.E6 (GND), U1.E8 (GND), U1.E10 (GND), U1.E14 (GND), U1.F5 (GND), U1.F7 (NC), U1.F9 (GND), U1.G3 (GND), U1.G6 (GND), U1.G7 (NC), U1.G8 (NC), U1.G10 (GND), U1.G12 (GND), U1.H5 (GND), U1.H7 (NC), U1.H8 (NC), U1.H9 (GND), U1.J6 (GND), U1.J7 (DXN_0), U1.J8 (DXP_0), U1.J10 (GND), U1.K1 (GND), U1.K5 (GND), U1.K7 (GND), U1.K9 (GND), U1.K14 (GND), U1.L4 (GND), U1.L6 (GND), U1.L8 (GND), U1.L10 (GND), U1.L11 (GND), U1.N3 (GND), U1.N5 (GND), U1.N9 (GND), U1.N12 (GND), U1.P1 (GND), U1.P14 (GND), U2.4 (VSS), X1.2 (GND); also elsewhere on the board
H3: U1.H3 (IO_L13N_T2_MRCC_34); also elsewhere on the board
H4: U1.H4 (IO_L13P_T2_MRCC_34); also elsewhere on the board
INIT: R6.1, U1.P8 (INIT_B_0)
J1: U1.J1 (IO_L15N_T2_DQS_34); also elsewhere on the board
J2: U1.J2 (IO_L15P_T2_DQS_34); also elsewhere on the board
J3: U1.J3 (IO_L17N_T2_34); also elsewhere on the board
J4: U1.J4 (IO_L17P_T2_34); also elsewhere on the board
K3: U1.K3 (IO_L16N_T2_34); also elsewhere on the board
K4: U1.K4 (IO_L16P_T2_34); also elsewhere on the board
L1: U1.L1 (IO_L18N_T2_34); also elsewhere on the board
L2: U1.L2 (IO_L22N_T3_34); also elsewhere on the board
L3: U1.L3 (IO_L22P_T3_34); also elsewhere on the board
LED: LED.A, U1.M10 (IO_25_14)
M0_0: R16.2, U1.M7 (M0_0)
M1: U1.M1 (IO_L18P_T2_34); also elsewhere on the board
M1_0: R5.1, U1.M8 (M1_0)
M2: U1.M2 (IO_L19N_T3_VREF_34); also elsewhere on the board
M2_0: R4.1, U1.M9 (M2_0)
M3: U1.M3 (IO_L19P_T3_34); also elsewhere on the board
N1: U1.N1 (IO_L20N_T3_34); also elsewhere on the board
unnamed: L3.1, U1.F8 (NC)
unnamed: LED.C, R12.2
unnamed: R1.2, R2.1, U2.7 (IO3/RESET#)
unnamed: R7.2, U1.N7 (CFGBVS_0)
unnamed: R3.2, U2.5 (SI/IO0)
unnamed: R9.1, U2.2 (SO/IO1)
unnamed: R10.1, R11.1, U2.3 (WP#/IO2)
unnamed: P5.TP, U1.P5 (IO_L24P_T3_34)
unnamed: N4.TP, U1.N4 (IO_L24N_T3_34)
unnamed: DONE.C, R24.2
unnamed: JTAG.5, R18.1
unnamed: JTAG.3, R21.1
unnamed: JTAG.6, R15.1
P2: U1.P2 (IO_L20P_T3_34); also elsewhere on the board
P3: U1.P3 (IO_L21N_T3_DQS_34); also elsewhere on the board
P4: U1.P4 (IO_L21P_T3_DQS_34); also elsewhere on the board
PROG: R17.2, U1.L7 (PROGRAM_B_0)
PROG_DONE: R24.1, R25.1, U1.P9 (DONE_0)
TCK: R21.2, U1.A7 (TCK_0)
TDI: R18.2, U1.P7 (TDI_0)
TDO: JTAG.4, U1.P6 (TDO_0)
TMS: R15.2, U1.M6 (TMS_0)
UART_CTS: U1.A10 (IO_L3N_T0_DQS_EMCCLK_14); also elsewhere on the board
UART_RTS: U1.B10 (IO_L3P_T0_DQS_PUDC_B_14); also elsewhere on the board
UART_RX: U1.A13 (IO_L4N_T0_D05_14); also elsewhere on the board
UART_TX: U1.A12 (IO_L4P_T0_D04_14); also elsewhere on the board
VIO_34: B34.2, C9.2, C10.2, C11.2, C14.2, U1.G2 (VCCO_34), U1.K2 (VCCO_34), U1.N2 (VCCO_34)

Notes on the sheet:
GNDADC
VCCADC
VCCBATT
VP_0
VN_0
VREFP_0
VREFN_0

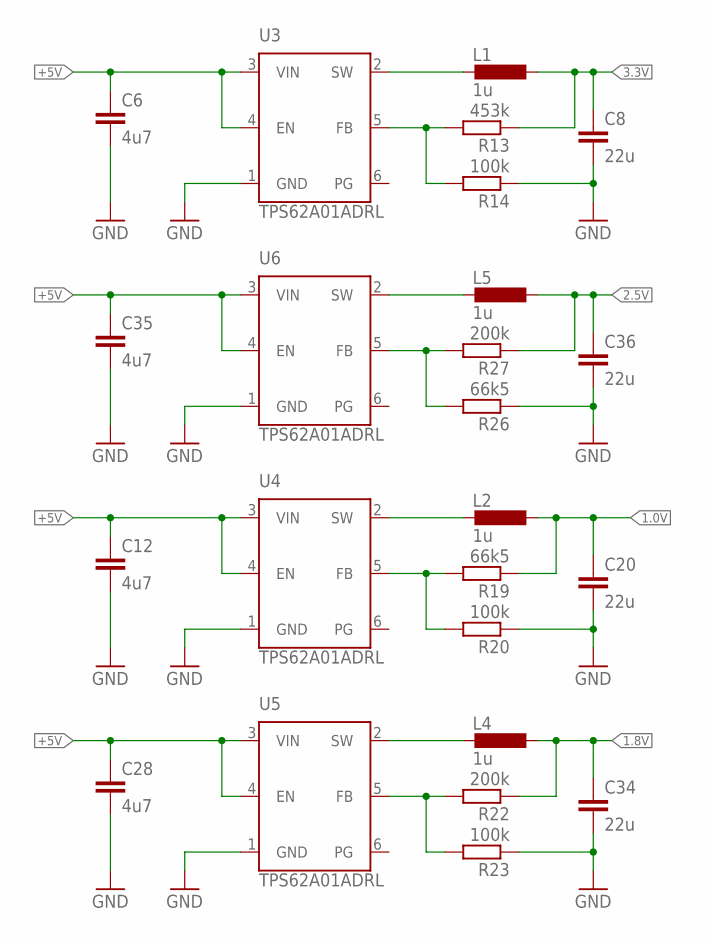
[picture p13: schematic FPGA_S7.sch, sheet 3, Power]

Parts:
C6, C12, C28, C35: 4u7; C0603; LCSC C19666
C8, C20, C34, C36: 22u; C0603; LCSC C109448
L1, L2, L4, L5: 1u; L1008; MPN LQM2HPN1R0MG0L; DIGIKEY 490-5112-1-ND
R13: 453k; R0402; LCSC C137978
R14: 100k; R0402; DIGIKEY RMCF0402FT100KCT-ND
R19: 66k5; R0402; DIGIKEY RMCF0402FT66K5CT-ND
R20, R23: 100k; R0402; LCSC C60491
R22: 200k; R0402; LCSC C114763
R26: 66k5; R0402; DIGIKEY RMCF0402FT100KCT-ND
R27: 200k; R0402; LCSC C137978
U3, U4, U5, U6: TPS62A01ADRL; SOTFL50P160X60-6N; DIGIKEY 296-TPS62A01ADRLRCT-ND

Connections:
1.0V: C20.1, L2.1, R19.1; also elsewhere on the board
1.8V: C34.1, L4.1, R22.1; also elsewhere on the board
2.5V: C36.1, L5.1, R27.1; also elsewhere on the board
3.3V: C8.1, L1.1, R13.1; also elsewhere on the board
+5V: C6.1, C12.1, C28.1, C35.1, U3.3 (VIN), U3.4 (EN), U4.3 (VIN), U4.4 (EN), U5.3 (VIN), U5.4 (EN), U6.3 (VIN), U6.4 (EN); also elsewhere on the board
GND: C6.2, C8.2, C12.2, C20.2, C28.2, C34.2, C35.2, C36.2, R14.1, R20.1, R23.1, R26.1, U3.1 (GND), U4.1 (GND), U5.1 (GND), U6.1 (GND); also elsewhere on the board
unnamed: L2.2, U4.2 (SW)
unnamed: L5.2, U6.2 (SW)
unnamed: R26.2, R27.2, U6.5 (FB)
unnamed: R19.2, R20.2, U4.5 (FB)
unnamed: R13.2, R14.2, U3.5 (FB)
unnamed: L4.2, U5.2 (SW)
unnamed: R22.2, R23.2, U5.5 (FB)
unnamed: L1.2, U3.2 (SW)



Board: 6 copper layers, 34.0 x 34.0 mm, 85 parts (59 on the bottom side), 130 nets.

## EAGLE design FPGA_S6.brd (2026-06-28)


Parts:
J1: DF17(2.0)-70DP-0.5V(57); DIGIKEY H11133CT-ND
J2: DF17(3.0)-70DS-0.5V(57); DIGIKEY H11112CT-ND

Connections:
+5V: J1.1, J1.2, J1.3, J1.4, J1.5, J1.6, J2.65, J2.66, J2.67, J2.68, J2.69, J2.70; also elsewhere on the board
FPGA_B15: J1.67; also elsewhere on the board
FPGA_B16: J1.65; also elsewhere on the board
FPGA_C15: J1.61; also elsewhere on the board
FPGA_C16: J1.59; also elsewhere on the board
FPGA_D14: J1.55; also elsewhere on the board
FPGA_D16: J1.53; also elsewhere on the board
FPGA_E12: J1.68; also elsewhere on the board
FPGA_E13: J1.66; also elsewhere on the board
FPGA_E15: J1.47; also elsewhere on the board
FPGA_E16: J1.49; also elsewhere on the board
FPGA_F13: J1.62; also elsewhere on the board
FPGA_F14: J1.60; also elsewhere on the board
FPGA_F15: J1.41; also elsewhere on the board
FPGA_F16: J1.43; also elsewhere on the board
FPGA_G12: J1.56; also elsewhere on the board
FPGA_H11: J1.54; also elsewhere on the board
FPGA_H13: J1.50; also elsewhere on the board
FPGA_H14: J1.48; also elsewhere on the board
FPGA_H15: J1.35; also elsewhere on the board
FPGA_H16: J1.37; also elsewhere on the board
FPGA_J11: J1.44; also elsewhere on the board
FPGA_J12: J1.42; also elsewhere on the board
FPGA_J13: J1.38; also elsewhere on the board
FPGA_J14: J1.23; also elsewhere on the board
FPGA_J16: J1.25; also elsewhere on the board
FPGA_K11: J1.30; also elsewhere on the board
FPGA_K12: J1.32; also elsewhere on the board
FPGA_K14: J1.36; also elsewhere on the board
FPGA_K15: J1.31; also elsewhere on the board
FPGA_K16: J1.29; also elsewhere on the board
FPGA_L10: J1.13; also elsewhere on the board
FPGA_L12: J1.24; also elsewhere on the board
FPGA_L13: J1.26; also elsewhere on the board
FPGA_M10: J1.14; also elsewhere on the board
FPGA_M13: J1.18; also elsewhere on the board
FPGA_M14: J1.20; also elsewhere on the board
FPGA_N9: J1.12; also elsewhere on the board
FPGA_P9: J1.10; also elsewhere on the board
FPGA_P15: J1.19; also elsewhere on the board
FPGA_P16: J1.17; also elsewhere on the board
FPGA_R9: J1.11; also elsewhere on the board
FPGA_T9: J1.9; also elsewhere on the board
FX3_?: J2.57; also elsewhere on the board
FX3_CTL0: J2.30; also elsewhere on the board
FX3_CTL1: J2.23; also elsewhere on the board
FX3_CTL2: J2.34; also elsewhere on the board
FX3_CTL3: J2.36; also elsewhere on the board
FX3_D0: J2.4; also elsewhere on the board
FX3_D1: J2.6; also elsewhere on the board
FX3_D2: J2.18; also elsewhere on the board
FX3_D3: J2.12; also elsewhere on the board
FX3_D4: J2.9; also elsewhere on the board
FX3_D5: J2.10; also elsewhere on the board
FX3_D6: J2.5; also elsewhere on the board
FX3_D7: J2.22; also elsewhere on the board
FX3_D8: J2.16; also elsewhere on the board
FX3_D9: J2.15; also elsewhere on the board
FX3_D10: J2.3; also elsewhere on the board
FX3_D11: J2.24; also elsewhere on the board
FX3_D12: J2.11; also elsewhere on the board
FX3_D13: J2.17; also elsewhere on the board
FX3_D14: J2.21; also elsewhere on the board
FX3_D15: J2.28; also elsewhere on the board
FX3_D16: J2.35; also elsewhere on the board
FX3_D17: J2.40; also elsewhere on the board
FX3_D18: J2.54; also elsewhere on the board
FX3_D19: J2.41; also elsewhere on the board
FX3_D20: J2.48; also elsewhere on the board
FX3_D21: J2.47; also elsewhere on the board
FX3_D22: J2.45; also elsewhere on the board
FX3_D23: J2.39; also elsewhere on the board
FX3_D24: J2.33; also elsewhere on the board
FX3_D25: J2.58; also elsewhere on the board
FX3_D26: J2.52; also elsewhere on the board
FX3_D27: J2.51; also elsewhere on the board
FX3_D28: J2.53; also elsewhere on the board
FX3_D29: J2.27; also elsewhere on the board
FX3_D30: J2.42; also elsewhere on the board
FX3_D31: J2.46; also elsewhere on the board
FX3_PCLK: J2.29; also elsewhere on the board
GND: J1.7, J1.8, J1.15, J1.16, J1.21, J1.22, J1.27, J1.28, J1.33, J1.34, J1.39, J1.40, J1.45, J1.46, J1.51, J1.52, J1.57, J1.58, J1.63, J1.64, J1.69, J1.70, J1.S1 (SHIELD), J1.S2 (SHIELD), J2.1, J2.2, J2.7, J2.8, J2.13, J2.14, J2.19, J2.20, J2.25, J2.26, J2.31, J2.32, J2.37, J2.38, J2.43, J2.44, J2.49, J2.50, J2.55, J2.56, J2.59, J2.60, J2.S1 (SHIELD), J2.S2 (SHIELD); also elsewhere on the board
UART_CTS: J2.63; also elsewhere on the board
UART_RTS: J2.61; also elsewhere on the board
UART_RX: J2.62; also elsewhere on the board
UART_TX: J2.64; also elsewhere on the board

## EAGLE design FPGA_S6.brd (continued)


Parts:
$$GND1: TPTP15R; TP15R
A9: TPTP15R; TP15R
AX: TPTP15R; TP15R
B1: SJ2W; SJ_2
BX: TPTP15R; TP15R
C1, C9, C19, C20, C21, C22, C32: 4u7; C0603; LCSC C19666
C2, C3, C4: 100n; C0402; LCSC C1525
C6, C17: 100u; C1206; DIGIKEY 490-GRM31CD80J107MEA8LCT-ND
C8, C10, C11, C13, C15, C16, C18, C24, C25, C27, C28, C29, C31, C34, C35: 470n; C0402; LCSC C162159
C14, C26: 47n; C0402; LCSC C327054
C33: 47u; C0805; LCSC C77072
CC9: TPTP15R; TP15R
DONE: RED; CHIP-LED0603; LCSC C7493803
GND: TPTP15R; TP15R
JTAG: PINHD-1X6_2.00; 1X06M
LED: RED; CHIP-LED0603; LCSC C7493803
R1, R2, R6, R7: 4k7; R0402; LCSC C25900
R3, R10, R11, R12, R13, R23, R24: 1k; R0402; LCSC C11702
R4, R8, R9, R16, R17, R20: 100R; R0402; LCSC C25076
R5: 2k4; R0402
U1: MCP9802A0T; SOT23-5L; FARNELL 1439487
U2: XC6SLX16-2FTG256I; FT256; DIGIKEY 122-1752-ND
U3: MT25QL128ABA1EW7-0SIT
U6: 24C00OT; SOT23-5L
X1: 50MHz; ASE; MPN_ ASE-50.000MHZ-E-T; FARNELL 2467898

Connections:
1.2V: C14.2, C15.2, C17.1, C20.2, C21.2, C25.2, C26.2, U2.G7 (VCCINT), U2.G9 (VCCINT), U2.H8 (VCCINT), U2.H10 (VCCINT), U2.J7 (VCCINT), U2.J9 (VCCINT), U2.K8 (VCCINT), U2.K10 (VCCINT); also elsewhere on the board
1.8V: B1.3, C33.2; also elsewhere on the board
3.3V: $$GND1.TP, B1.1, C1.2, C2.1, C3.1, C4.2, C6.1, C13.2, C16.2, C18.2, C19.2, C22.2, C24.2, C27.2, C28.2, C29.2, C31.2, C32.2, C34.2, C35.2, DONE.A, JTAG.1, R1.2, R2.1, R3.1, R5.2, R6.1, R7.1, R8.1, R11.1, R12.1, R24.2, U1.1 (VCC), U2.B4 (VCCO_0), U2.B9 (VCCO_0), U2.B13 (VCCO_0), U2.D2 (VCCO_3), U2.D7 (VCCO_0), U2.D10 (VCCO_0), U2.E5 (VCCAUX), U2.F8 (VCCAUX), U2.F11 (VCCAUX), U2.G4 (VCCO_3), U2.G10 (VCCAUX), U2.H6 (VCCAUX), U2.J2 (VCCO_3), U2.J10 (VCCAUX), U2.K4 (VCCO_3), U2.L6 (VCCAUX), U2.L9 (VCCAUX), U2.N2 (VCCO_3), U2.N7 (VCCO_2), U2.N10 (VCCO_2), U2.R4 (VCCO_2), U2.R8 (VCCO_2), U3.3 (!W), U3.7 (!HOLD), U3.8 (VCC), U6.4 (VCC), X1.4 (VDD); also elsewhere on the board
50MHZ: U2.T7 (IO_L32N_GCLK28_2), X1.3 (OUT)
CMPCS: R12.2, U2.L11 (CMPCS_B_2)
FLASH_!CS: R5.1, U2.T3 (IO_L65N_CSO_B_2), U3.1 (!S)
FLASH_MISO: R4.2, U2.P10 (IO_L3P_D0_DIN_MISO_MISO1_2)
FLASH_MOSI: U2.T10 (IO_L3N_MOSI_CSI_B_MISO0_2), U3.5 (DQ0)
FLASH_SCK: R8.2, R9.1, U2.R11 (IO_L1P_CCLK_2), U3.6 (C)
FPGA_B15: U2.B15 (IO_L29P_A23_M1A13_1); also elsewhere on the board
FPGA_B16: U2.B16 (IO_L29N_A22_M1A14_1); also elsewhere on the board
FPGA_C15: U2.C15 (IO_L33P_A15_M1A10_1); also elsewhere on the board
FPGA_C16: U2.C16 (IO_L33N_A14_M1A4_1); also elsewhere on the board
FPGA_D14: U2.D14 (IO_L31P_A19_M1CKE_1); also elsewhere on the board
FPGA_D16: U2.D16 (IO_L31N_A18_M1A12_1); also elsewhere on the board
FPGA_E12: U2.E12 (IO_L1N_A24_VREF_1); also elsewhere on the board
FPGA_E13: U2.E13 (IO_L1P_A25_1); also elsewhere on the board
FPGA_E15: U2.E15 (IO_L34P_A13_M1WE_1); also elsewhere on the board
FPGA_E16: U2.E16 (IO_L34N_A12_M1BA2_1); also elsewhere on the board
FPGA_F13: U2.F13 (IO_L32P_A17_M1A8_1); also elsewhere on the board
FPGA_F14: U2.F14 (IO_L32N_A16_M1A9_1); also elsewhere on the board
FPGA_F15: U2.F15 (IO_L35P_A11_M1A7_1); also elsewhere on the board
FPGA_F16: U2.F16 (IO_L35N_A10_M1A2_1); also elsewhere on the board
FPGA_G12: U2.G14 (IO_L36P_A9_M1BA0_1); also elsewhere on the board
FPGA_H11: U2.G16 (IO_L36N_A8_M1BA1_1); also elsewhere on the board
FPGA_H13: U2.H13 (IO_L39P_M1A3_1); also elsewhere on the board
FPGA_H14: U2.H14 (IO_L39N_M1ODT_1); also elsewhere on the board
FPGA_H15: U2.H15 (IO_L37P_A7_M1A0_1); also elsewhere on the board
FPGA_H16: U2.H16 (IO_L37N_A6_M1A1_1); also elsewhere on the board
FPGA_J11: U2.J11 (IO_L40P_GCLK11_M1A5_1); also elsewhere on the board
FPGA_J12: U2.J12 (IO_L40N_GCLK10_M1A6_1); also elsewhere on the board
FPGA_J13: U2.J13 (IO_L41P_GCLK9_IRDY1_M1RASN_1); also elsewhere on the board
FPGA_J14: U2.J14 (IO_L43P_GCLK5_M1DQ4_1); also elsewhere on the board
FPGA_J16: U2.J16 (IO_L43N_GCLK4_M1DQ5_1); also elsewhere on the board
FPGA_K11: U2.K11 (IO_L42N_GCLK6_TRDY1_M1LDM_1); also elsewhere on the board
FPGA_K12: U2.K12 (IO_L42P_GCLK7_M1UDM_1); also elsewhere on the board
FPGA_K14: U2.K14 (IO_L41N_GCLK8_M1CASN_1); also elsewhere on the board
FPGA_K15: U2.K15 (IO_L44P_A3_M1DQ6_1); also elsewhere on the board
FPGA_K16: U2.K16 (IO_L44N_A2_M1DQ7_1); also elsewhere on the board
FPGA_L10: U2.L10 (IO_L16P_2); also elsewhere on the board
FPGA_L12: U2.L12 (IO_L53P_1); also elsewhere on the board
FPGA_L13: U2.L13 (IO_L53N_VREF_1); also elsewhere on the board
FPGA_M10: U2.M10 (IO_L16N_VREF_2); also elsewhere on the board
FPGA_M13: U2.M13 (IO_L74P_AWAKE_1); also elsewhere on the board
FPGA_M14: U2.M14 (IO_L74N_DOUT_BUSY_1); also elsewhere on the board
FPGA_N9: U2.N9 (IO_L14P_D11_2); also elsewhere on the board
FPGA_P9: U2.P9 (IO_L14N_D12_2); also elsewhere on the board
FPGA_P15: U2.P15 (IO_L48P_HDC_M1DQ8_1); also elsewhere on the board
FPGA_P16: U2.P16 (IO_L48N_M1DQ9_1); also elsewhere on the board
FPGA_R9: U2.R9 (IO_L23P_2); also elsewhere on the board
FPGA_T9: U2.T9 (IO_L23N_2); also elsewhere on the board
FX3_?: U2.R1 (IO_L32N_M3DQ15_3); also elsewhere on the board
FX3_CTL0: U2.H5 (IO_L43N_GCLK22_IRDY2_M3CASN_3); also elsewhere on the board
FX3_CTL1: U2.E2 (IO_L46P_M3CLK_3); also elsewhere on the board
FX3_CTL2: U2.H4 (IO_L44P_GCLK21_M3A5_3); also elsewhere on the board
FX3_CTL3: U2.H3 (IO_L44N_GCLK20_M3A6_3); also elsewhere on the board
FX3_D0: U2.A3 (IO_L83N_VREF_3); also elsewhere on the board
FX3_D1: U2.B3 (IO_L83P_3); also elsewhere on the board
FX3_D2: U2.E3 (IO_L54N_M3A11_3); also elsewhere on the board
FX3_D3: U2.F5 (IO_L55N_M3A14_3); also elsewhere on the board
FX3_D4: U2.B1 (IO_L50N_M3BA2_3); also elsewhere on the board
FX3_D5: U2.F6 (IO_L55P_M3A13_3); also elsewhere on the board
FX3_D6: U2.B2 (IO_L52P_M3A8_3); also elsewhere on the board
FX3_D7: U2.G6 (IO_L51P_M3A10_3); also elsewhere on the board
FX3_D8: U2.E4 (IO_L54P_M3RESET_3); also elsewhere on the board
FX3_D9: U2.D1 (IO_L49N_M3A2_3); also elsewhere on the board
FX3_D10: U2.A2 (IO_L52N_M3A9_3); also elsewhere on the board
FX3_D11: U2.G5 (IO_L51N_M3A4_3); also elsewhere on the board
FX3_D12: U2.C1 (IO_L50P_M3WE_3); also elsewhere on the board
FX3_D13: U2.D3 (IO_L49P_M3A7_3); also elsewhere on the board
FX3_D14: U2.E1 (IO_L46N_M3CLKN_3); also elsewhere on the board
FX3_D15: U2.J6 (IO_L43P_GCLK23_M3RASN_3); also elsewhere on the board
FX3_D16: U2.J4 (IO_L42N_GCLK24_M3LDM_3); also elsewhere on the board
FX3_D17: U2.L5 (IO_L45N_M3ODT_3); also elsewhere on the board
FX3_D18: U2.N4 (IO_L2N_3); also elsewhere on the board
FX3_D19: U2.K1 (IO_L37N_M3DQ1_3); also elsewhere on the board
FX3_D20: U2.M3 (IO_L1N_VREF_3); also elsewhere on the board
FX3_D21: U2.M1 (IO_L35N_M3DQ11_3); also elsewhere on the board
FX3_D22: U2.M2 (IO_L35P_M3DQ10_3); also elsewhere on the board
FX3_D23: U2.K2 (IO_L37P_M3DQ0_3); also elsewhere on the board
FX3_D24: U2.K3 (IO_L42P_GCLK25_TRDY2_M3UDM_3); also elsewhere on the board
FX3_D25: U2.R2 (IO_L32P_M3DQ14_3); also elsewhere on the board
FX3_D26: U2.M5 (IO_L2P_3); also elsewhere on the board
FX3_D27: U2.P2 (IO_L33P_M3DQ12_3); also elsewhere on the board
FX3_D28: U2.P1 (IO_L33N_M3DQ13_3); also elsewhere on the board
FX3_D29: U2.F1 (IO_L41N_GCLK26_M3DQ5_3); also elsewhere on the board
FX3_D30: U2.L4 (IO_L45P_M3A3_3); also elsewhere on the board
FX3_D31: U2.M4 (IO_L1P_3); also elsewhere on the board
FX3_PCLK: U2.F2 (IO_L41P_GCLK27_M3DQ4_3); also elsewhere on the board
GND: C1.1, C2.2, C3.2, C4.1, C6.2, C8.1, C9.1, C10.1, C11.1, C13.1, C14.1, C15.1, C16.1, C17.2, C18.1, C19.1, C20.1, C21.1, C22.1, C24.1, C25.1, C26.1, C27.1, C28.1, C29.1, C31.1, C32.1, C33.1, C34.1, C35.1, GND.TP, JTAG.2, R9.2, R10.2, R13.1, U1.2 (GND), U2.A1 (GND), U2.A16 (GND), U2.B7 (GND), U2.B11 (GND), U2.D4 (GND), U2.D13 (GND), U2.E9 (GND), U2.G2 (GND), U2.G8 (GND), U2.G15 (GND), U2.H7 (GND), U2.H9 (GND), U2.H12 (GND), U2.J5 (GND), U2.J8 (GND), U2.K7 (GND), U2.K9 (GND), U2.L2 (GND), U2.L15 (GND), U2.M8 (GND), U2.N13 (GND), U2.P3 (GND), U2.P14 (SUSPEND), U2.R6 (GND), U2.R10 (GND), U2.T1 (GND), U2.T16 (GND), U3.4 (VSS), U3.EP, U6.2 (GND), X1.2 (GND); also elsewhere on the board
HSWAPEN: R3.2, U2.C4 (IO_L1P_HSWAPEN_0)
INIT: R1.1, U2.R3 (IO_L65P_INIT_B_2)
LED: LED.A, U2.A13 (IO_L63N_SCP6_0)
M0_0: R11.2, U2.T11 (IO_L1N_M0_CMPMISO_2)
M1_0: R10.1, U2.N11 (IO_L13P_M1_2)
unnamed: BX.TP, U2.B10 (IO_L35P_GCLK17_0)
unnamed: LED.C, R13.2
unnamed: R4.1, U3.2 (DQ1)
unnamed: AX.TP, U2.A10 (IO_L35N_GCLK16_0)
unnamed: A9.TP, U2.A9 (IO_L34N_GCLK18_0)
unnamed: CC9.TP, U2.C9 (IO_L34P_GCLK19_0)
unnamed: DONE.C, R23.2
unnamed: JTAG.5, R17.1
unnamed: JTAG.3, R20.1
unnamed: JTAG.6, R16.1
PROG: R2.2, U2.T2 (PROGRAM_B_2)
PROG_DONE: R23.1, R24.1, U2.P13 (DONE_2)
SCL: R6.2, U1.4 (SCL), U2.A5 (IO_L2N_0), U6.1 (SCL)
SDA: R7.2, U1.5 (SDA), U2.A4 (IO_L1N_VREF_0), U6.3 (SDA)
TCK: R20.2, U2.C14 (TCK)
TDI: R17.2, U2.C12 (TDI)
TDO: JTAG.4, U2.E14 (TDO)
TMS: R16.2, U2.A15 (TMS)
UART_CTS: U2.T6 (IO_L47N_2); also elsewhere on the board
UART_RTS: U2.P6 (IO_L47P_2); also elsewhere on the board
UART_RX: U2.R5 (IO_L48P_D7_2); also elsewhere on the board
UART_TX: U2.T5 (IO_L48N_RDWR_B_VREF_2); also elsewhere on the board
VIO_B1: B1.2, C8.2, C9.2, C10.2, C11.2, U2.D15 (VCCO_1), U2.G13 (VCCO_1), U2.J15 (VCCO_1), U2.K13 (VCCO_1), U2.N15 (VCCO_1), U2.R13 (VCCO_1)


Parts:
C5, C12, C30: 4u7; C0603; LCSC C19666
C7, C23, C36: 22u; C0603; LCSC C109448
L1, L2, L3: 1u; L1008; MPN LQM2HPN1R0MG0L; DIGIKEY 490-5112-1-ND
R14: 453k; R0402; LCSC C137978
R15: 100k; R0402; DIGIKEY RMCF0402FT100KCT-ND
R18: 100k; R0402; DIGIKEY RMCF0402FT66K5CT-ND
R19, R22: 100k; R0402; LCSC C60491
R21: 200k; R0402; LCSC C114763
U4, U5, U7: TPS62A01ADRL; SOTFL50P160X60-6N; DIGIKEY 296-TPS62A01ADRLRCT-ND

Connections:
1.2V: C23.1, L2.1, R18.1; also elsewhere on the board
1.8V: C36.1, L3.1, R21.1; also elsewhere on the board
3.3V: C7.1, L1.1, R14.1; also elsewhere on the board
+5V: C5.1, C12.1, C30.1, U4.3 (VIN), U4.4 (EN), U5.3 (VIN), U5.4 (EN), U7.3 (VIN), U7.4 (EN); also elsewhere on the board
GND: C5.2, C7.2, C12.2, C23.2, C30.2, C36.2, R15.1, R19.1, R22.1, U4.1 (GND), U5.1 (GND), U7.1 (GND); also elsewhere on the board
unnamed: L2.2, U5.2 (SW)
unnamed: R18.2, R19.2, U5.5 (FB)
unnamed: R14.2, R15.2, U4.5 (FB)
unnamed: L3.2, U7.2 (SW)
unnamed: R21.2, R22.2, U7.5 (FB)
unnamed: L1.2, U4.2 (SW)



Board: 6 copper layers, 34.0 x 34.0 mm, 83 parts (54 on the bottom side), 125 nets.

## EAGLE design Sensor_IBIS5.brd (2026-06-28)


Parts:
C1, C2, C13, C14, C15, C29: 10u; C0603
C3, C4, C5, C6, C8, C10, C16, C18, C30, C31, C32, C33: 100n; C0402; LCSC C1525
C7, C19, C21, C22, C23: 1u; C0402
C9, C12, C25: 68p; C0402; LCSC C1525
C11, C20, C24, C27, C28: 4u7; C0603; LCSC C19666
C17, C26: 100u; C1206; DIGIKEY 490-GRM31CD80J107MEA8LCT-ND
J1: DF17(3.0)-70DS-0.5V(57)
Q1: 40MHz; 3.2X2.5_KXO-V96; DIGIKEY 1473-SIT8208AC-23-33E-72.000000-ND
R1, R2, R12, R13, R18, R21, R22, R24: 50k; R0402
R3: 360R; R0402
R4, R5, R16, R17, R19, R20: 0R; R0402
R6, R23: 25k; R0402
R7, R8, R14: 100k; R0402
R9: 1k2; R0402
R10: 164k; R0402
R11, R15: ?; R0402
U1: CYII5FM1300AB; LCC-84
U2, U4: ADP3335ARMZ-3.3; MSOP08; DIGIKEY 505-ADP3335ARMZ-3.3RL7CT-ND
U3: ADP3335ARMZ-1.8; MSOP08; DIGIKEY 505-ADP3335ARMZ-1.8-R7CT-ND

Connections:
!RESET: J1.55, R24.2, U1.23 (SYS_RESET)
+5V: C1.1, C2.1, C15.1, J1.1, J1.2, J1.3, J1.4, J1.5, J1.6, U2.7 (IN), U2.8 (IN), U3.7 (IN), U3.8 (IN), U4.7 (IN), U4.8 (IN)
ADC_CLK: R4.2, R5.1, U1.58 (ADC_CLK)
ADC_CLK_EXT: J1.14, R4.1
CLK: Q1.3 (OUT), R5.2, R17.2
DATA_0: J1.47, U1.68 (ADC_OUT0)
DATA_1: J1.43, U1.67 (ADC_OUT1)
DATA_2: J1.41, U1.66 (ADC_OUT2)
DATA_3: J1.37, U1.65 (ADC_OUT3)
DATA_4: J1.35, U1.64 (ADC_OUT4)
DATA_5: J1.31, U1.63 (ADC_OUT5)
DATA_6: J1.29, U1.62 (ADC_OUT6)
DATA_7: J1.25, U1.61 (ADC_OUT7)
DATA_8: J1.23, U1.60 (ADC_OUT8)
DATA_9: J1.19, U1.59 (ADC_OUT9)
EL_BLACK: J1.53, U1.24 (EL_BLACK)
EN_3V0: J1.11, R12.2, U4.6 (!SD)
EN_3V3: J1.9, R1.2, U2.6 (!SD)
EN_4V5: J1.67, R2.2, U3.6 (!SD)
EN_CLK: J1.10, Q1.1 (TS), R13.2
EOSX: J1.12, U1.25 (EOSX)
GND: C1.2, C2.2, C3.2, C4.2, C5.2, C6.2, C7.2, C8.2, C10.2, C11.2, C13.2, C14.2, C15.2, C16.2, C17.2, C18.2, C19.2, C20.2, C21.2, C22.2, C23.2, C24.2, C26.2, C27.2, C28.2, C29.2, C30.2, C31.2, C32.2, C33.2, J1.7, J1.8, J1.15, J1.16, J1.21, J1.22, J1.27, J1.28, J1.33, J1.34, J1.39, J1.40, J1.45, J1.46, J1.51, J1.52, J1.57, J1.58, J1.63, J1.64, J1.69, J1.70, J1.S1 (SHIELD), J1.S2 (SHIELD), Q1.2 (GND), R1.1, R2.1, R7.1, R8.1, R9.1, R12.1, R13.1, R14.1, R20.1, R24.1, U1.1 (P_DATA_8), U1.2 (P_WR), U1.5 (S_EN), U1.6 (SER_MODE), U1.9 (GNDA), U1.10 (GNDD), U1.12 (IF_MODE), U1.34 (GNDD), U1.35 (GNDA), U1.38 (P_DATA_0), U1.39 (P_DATA_1), U1.40 (P_DATA_2), U1.41 (P_DATA_3), U1.42 (P_DATA_4), U1.43 (P_DATA_5), U1.44 (P_DATA_6), U1.45 (P_DATA_7), U1.46 (SI2_ADDR_0), U1.47 (SI2_ADDR_1), U1.48 (SI2_ADDR_2), U1.49 (SI2_ADDR_3), U1.50 (SI2_ADDR_4), U1.51 (GNDAB), U1.54 (ADC_GNDA), U1.56 (ADC_GNDD), U1.72 (ADC_GNDA), U1.73 (ADC_GNDD), U1.78 (P_DATA_15), U1.79 (P_DATA_14), U1.80 (P_DATA_13), U1.81 (P_DATA_12), U1.82 (P_DATA_11), U1.83 (P_DATA_10), U1.84 (P_DATA_9), U2.4 (GND), U3.4 (GND), U4.4 (GND)
LAST_LINE: J1.56, U1.16 (LAST_LINE)
unnamed: U1.28 (PXL_OUT1), U1.69 (ADC_IN)
unnamed: C18.1, U4.5 (NR)
unnamed: C5.1, U3.5 (NR)
unnamed: C4.1, U2.5 (NR)
unnamed: R19.2, U1.26 (DAC_VHIGH)
unnamed: R20.2, U1.27 (DAC_VLOW)
unnamed: C30.1, R18.2, U1.13 (DEC_CMD)
unnamed: C32.1, R22.2, U1.31 (COL_CMD)
unnamed: C33.1, R23.2, U1.32 (PC_CMD)
unnamed: C31.1, R21.2, U1.30 (AMP_CMD)
unnamed: C6.1, R6.2, U1.70 (ADC_CMD)
unnamed: C3.1, R3.2, U1.75 (ADC_VHIGH)
unnamed: C8.1, R9.2, U1.53 (ADC_VLOW)
unnamed: C7.1, U1.52 (VDDR_RIGHT)
unnamed: C12.2, R8.2, R11.2, U3.3 (ADJ)
unnamed: C9.2, R7.2, R10.2, U2.3 (ADJ)
unnamed: C25.2, R14.2, R15.2, U4.3 (ADJ)
PXL_VALID: J1.50, U1.19 (PXL_VALID)
SCL: J1.68, U1.3 (S_CLK)
SDA: J1.66, U1.4 (S_DATA)
SS_START: J1.65, U1.20 (SS_START)
SS_STOP: J1.61, U1.21 (SS_STOP)
SYS_CLK: R16.2, R17.1, U1.18 (SYS_CLK)
SYS_CLK_EXT: J1.20, R16.1
TIME_OUT: J1.59, U1.22 (TIME_OUT)
VDD_3V0: C17.1, C19.1, C20.1, C22.1, C24.1, C25.1, C29.1, R15.1, U1.7 (VDDC), U1.37 (VDDC), U4.1 (OUT), U4.2 (OUT)
VDD_3V3: C9.1, C13.1, C16.1, C21.1, C23.1, C26.1, C27.1, C28.1, Q1.4 (VDD), R3.1, R6.1, R10.1, R18.1, R19.1, R21.1, R22.1, R23.1, U1.8 (VDDA), U1.11 (VDDD), U1.33 (VDDD), U1.36 (VDDA), U1.55 (ADC_VDDA), U1.57 (ADC_VDDD), U1.71 (ADC_VDDD), U1.74 (ADC_VDDA), U2.1 (OUT), U2.2 (OUT)
VDD_4V5: C10.1, C11.1, C12.1, C14.1, R11.1, U1.76 (VDDR_LEFT), U1.77 (VDDH), U3.1 (OUT), U3.2 (OUT)
Y_CLOCK: J1.60, U1.15 (Y_CLOCK)
Y_LOAD: J1.54, U1.17 (X_LOAD)
Y_START: J1.62, U1.14 (Y_START)



Board: 4 copper layers, 34.0 x 34.0 mm, 63 parts (62 on the bottom side), 54 nets.

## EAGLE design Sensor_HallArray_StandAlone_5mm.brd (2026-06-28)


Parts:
C1, C2, C3, C4, C5, C6, C7, C8, C9, C10, C11, C12, C13, C14, C15, C16, C17, C18, C19, C20, C21, C22, C23, C24, C25, C26, C27, C28, C29, C30, C31, C32, C33, C34, C35, C36, C37, C38, C39, C40, C41, C42, C43, C44, C45, C46, C47, C48, C49, C50, C51, C52, C53, C54, C55, C56: C-EUC0402; C0402
U1, U2, U3, U4, U5, U6, U7, U8, U9, U10, U11, U12, U13, U14, U15, U16, U17, U18, U19, U20, U21, U22, U23, U24, U25, U26, U27, U28, U29, U30, U31, U32, U33, U34, U35, U36, U37, U38, U39, U40, U41, U42, U43, U44, U45, U46, U47, U48, U49, U50, U51, U52, U53, U54, U55, U56, U57, U58, U59, U60, U61, U62, U63, U64: A1301LH; SOT23-W
U65, U66, U67, U68, U69, U70, U71, U72, U73, U74, U75, U76, U77, U78, U79, U80, U81, U82, U83, U84, U85, U86, U87, U88, U89, U90, U91, U92, U93, U94, U95, U96, U97, U98, U99, U100, U101, U102, U103, U104, U105, U106, U107, U108, U109, U110, U111, U112, U113, U114, U115, U116, U117, U118, U119, U120, U121, U122, U123, U124, U125, U126, U127, U128: 741G66DCK; SC70-5
X1: FH12-20S-0.5SH

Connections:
COL0: U72.4 (E), U80.4 (E), U88.4 (E), U96.4 (E), U104.4 (E), U112.4 (E), U120.4 (E), U128.4 (E), X1.13
COL1: U71.4 (E), U79.4 (E), U87.4 (E), U95.4 (E), U103.4 (E), U111.4 (E), U119.4 (E), U127.4 (E), X1.14
COL2: U70.4 (E), U78.4 (E), U86.4 (E), U94.4 (E), U102.4 (E), U110.4 (E), U118.4 (E), U126.4 (E), X1.15
COL3: U69.4 (E), U77.4 (E), U85.4 (E), U93.4 (E), U101.4 (E), U109.4 (E), U117.4 (E), U125.4 (E), X1.16
COL4: U68.4 (E), U76.4 (E), U84.4 (E), U92.4 (E), U100.4 (E), U108.4 (E), U116.4 (E), U124.4 (E), X1.17
COL5: U67.4 (E), U75.4 (E), U83.4 (E), U91.4 (E), U99.4 (E), U107.4 (E), U115.4 (E), U123.4 (E), X1.18
COL6: U66.4 (E), U74.4 (E), U82.4 (E), U90.4 (E), U98.4 (E), U106.4 (E), U114.4 (E), U122.4 (E), X1.19
COL7: U65.4 (E), U73.4 (E), U81.4 (E), U89.4 (E), U97.4 (E), U105.4 (E), U113.4 (E), U121.4 (E), X1.20
GND: C1.2, C2.2, C3.2, C4.2, C5.2, C6.2, C7.2, C8.2, C9.2, C10.2, C11.2, C12.2, C13.2, C14.2, C15.2, C16.2, C17.2, C18.2, C19.2, C20.2, C21.2, C22.2, C23.2, C24.2, C25.2, C26.2, C27.2, C28.2, C29.2, C30.2, C31.2, C32.2, C33.2, C34.2, C35.2, C36.2, C37.2, C38.2, C39.2, C40.2, C41.2, C42.2, C43.2, C44.2, C45.2, C46.2, C47.2, C48.2, C49.2, C50.2, C51.2, C52.2, C53.2, C54.2, C55.2, C56.2, U1.3 (GND), U2.3 (GND), U3.3 (GND), U4.3 (GND), U5.3 (GND), U6.3 (GND), U7.3 (GND), U8.3 (GND), U9.3 (GND), U10.3 (GND), U11.3 (GND), U12.3 (GND), U13.3 (GND), U14.3 (GND), U15.3 (GND), U16.3 (GND), U17.3 (GND), U18.3 (GND), U19.3 (GND), U20.3 (GND), U21.3 (GND), U22.3 (GND), U23.3 (GND), U24.3 (GND), U25.3 (GND), U26.3 (GND), U27.3 (GND), U28.3 (GND), U29.3 (GND), U30.3 (GND), U31.3 (GND), U32.3 (GND), U33.3 (GND), U34.3 (GND), U35.3 (GND), U36.3 (GND), U37.3 (GND), U38.3 (GND), U39.3 (GND), U40.3 (GND), U41.3 (GND), U42.3 (GND), U43.3 (GND), U44.3 (GND), U45.3 (GND), U46.3 (GND), U47.3 (GND), U48.3 (GND), U49.3 (GND), U50.3 (GND), U51.3 (GND), U52.3 (GND), U53.3 (GND), U54.3 (GND), U55.3 (GND), U56.3 (GND), U57.3 (GND), U58.3 (GND), U59.3 (GND), U60.3 (GND), U61.3 (GND), U62.3 (GND), U63.3 (GND), U64.3 (GND), U65.3 (GND), U66.3 (GND), U67.3 (GND), U68.3 (GND), U69.3 (GND), U70.3 (GND), U71.3 (GND), U72.3 (GND), U73.3 (GND), U74.3 (GND), U75.3 (GND), U76.3 (GND), U77.3 (GND), U78.3 (GND), U79.3 (GND), U80.3 (GND), U81.3 (GND), U82.3 (GND), U83.3 (GND), U84.3 (GND), U85.3 (GND), U86.3 (GND), U87.3 (GND), U88.3 (GND), U89.3 (GND), U90.3 (GND), U91.3 (GND), U92.3 (GND), U93.3 (GND), U94.3 (GND), U95.3 (GND), U96.3 (GND), U97.3 (GND), U98.3 (GND), U99.3 (GND), U100.3 (GND), U101.3 (GND), U102.3 (GND), U103.3 (GND), U104.3 (GND), U105.3 (GND), U106.3 (GND), U107.3 (GND), U108.3 (GND), U109.3 (GND), U110.3 (GND), U111.3 (GND), U112.3 (GND), U113.3 (GND), U114.3 (GND), U115.3 (GND), U116.3 (GND), U117.3 (GND), U118.3 (GND), U119.3 (GND), U120.3 (GND), U121.3 (GND), U122.3 (GND), U123.3 (GND), U124.3 (GND), U125.3 (GND), U126.3 (GND), U127.3 (GND), U128.3 (GND), X1.9, X1.10
unnamed: U1.2 (OUT), U128.1 (Y)
unnamed: U2.2 (OUT), U127.1 (Y)
unnamed: U9.2 (OUT), U120.1 (Y)
unnamed: U3.2 (OUT), U126.1 (Y)
unnamed: U4.2 (OUT), U125.1 (Y)
unnamed: U5.2 (OUT), U124.1 (Y)
unnamed: U6.2 (OUT), U123.1 (Y)
unnamed: U7.2 (OUT), U122.1 (Y)
unnamed: U8.2 (OUT), U121.1 (Y)
unnamed: U10.2 (OUT), U119.1 (Y)
unnamed: U11.2 (OUT), U118.1 (Y)
unnamed: U12.2 (OUT), U117.1 (Y)
unnamed: U13.2 (OUT), U116.1 (Y)
unnamed: U14.2 (OUT), U115.1 (Y)
unnamed: U15.2 (OUT), U114.1 (Y)
unnamed: U16.2 (OUT), U113.1 (Y)
unnamed: U17.2 (OUT), U112.1 (Y)
unnamed: U18.2 (OUT), U111.1 (Y)
unnamed: U19.2 (OUT), U110.1 (Y)
unnamed: U20.2 (OUT), U109.1 (Y)
unnamed: U21.2 (OUT), U108.1 (Y)
unnamed: U22.2 (OUT), U107.1 (Y)
unnamed: U23.2 (OUT), U106.1 (Y)
unnamed: U24.2 (OUT), U105.1 (Y)
unnamed: U25.2 (OUT), U104.1 (Y)
unnamed: U26.2 (OUT), U103.1 (Y)
unnamed: U27.2 (OUT), U102.1 (Y)
unnamed: U28.2 (OUT), U101.1 (Y)
unnamed: U29.2 (OUT), U100.1 (Y)
unnamed: U30.2 (OUT), U99.1 (Y)
unnamed: U31.2 (OUT), U98.1 (Y)
unnamed: U32.2 (OUT), U97.1 (Y)
unnamed: U33.2 (OUT), U96.1 (Y)
unnamed: U34.2 (OUT), U95.1 (Y)
unnamed: U35.2 (OUT), U94.1 (Y)
unnamed: U36.2 (OUT), U93.1 (Y)
unnamed: U37.2 (OUT), U92.1 (Y)
unnamed: U38.2 (OUT), U91.1 (Y)
unnamed: U39.2 (OUT), U90.1 (Y)
unnamed: U40.2 (OUT), U89.1 (Y)
unnamed: U41.2 (OUT), U88.1 (Y)
unnamed: U42.2 (OUT), U87.1 (Y)
unnamed: U43.2 (OUT), U86.1 (Y)
unnamed: U44.2 (OUT), U85.1 (Y)
unnamed: U45.2 (OUT), U84.1 (Y)
unnamed: U46.2 (OUT), U83.1 (Y)
unnamed: U47.2 (OUT), U82.1 (Y)
unnamed: U48.2 (OUT), U81.1 (Y)
unnamed: U49.2 (OUT), U80.1 (Y)
unnamed: U50.2 (OUT), U79.1 (Y)
unnamed: U51.2 (OUT), U78.1 (Y)
unnamed: U52.2 (OUT), U77.1 (Y)
unnamed: U53.2 (OUT), U76.1 (Y)
unnamed: U54.2 (OUT), U75.1 (Y)
unnamed: U55.2 (OUT), U74.1 (Y)
unnamed: U56.2 (OUT), U73.1 (Y)
unnamed: U57.2 (OUT), U72.1 (Y)
unnamed: U58.2 (OUT), U71.1 (Y)
unnamed: U59.2 (OUT), U70.1 (Y)
unnamed: U60.2 (OUT), U69.1 (Y)
unnamed: U61.2 (OUT), U68.1 (Y)
unnamed: U62.2 (OUT), U67.1 (Y)
unnamed: U63.2 (OUT), U66.1 (Y)
unnamed: U64.2 (OUT), U65.1 (Y)
ROW0: U121.2 (Z), U122.2 (Z), U123.2 (Z), U124.2 (Z), U125.2 (Z), U126.2 (Z), U127.2 (Z), U128.2 (Z), X1.1
ROW1: U113.2 (Z), U114.2 (Z), U115.2 (Z), U116.2 (Z), U117.2 (Z), U118.2 (Z), U119.2 (Z), U120.2 (Z), X1.2
ROW2: U105.2 (Z), U106.2 (Z), U107.2 (Z), U108.2 (Z), U109.2 (Z), U110.2 (Z), U111.2 (Z), U112.2 (Z), X1.3
ROW3: U97.2 (Z), U98.2 (Z), U99.2 (Z), U100.2 (Z), U101.2 (Z), U102.2 (Z), U103.2 (Z), U104.2 (Z), X1.4
ROW4: U89.2 (Z), U90.2 (Z), U91.2 (Z), U92.2 (Z), U93.2 (Z), U94.2 (Z), U95.2 (Z), U96.2 (Z), X1.5
ROW5: U81.2 (Z), U82.2 (Z), U83.2 (Z), U84.2 (Z), U85.2 (Z), U86.2 (Z), U87.2 (Z), U88.2 (Z), X1.6
ROW6: U73.2 (Z), U74.2 (Z), U75.2 (Z), U76.2 (Z), U77.2 (Z), U78.2 (Z), U79.2 (Z), U80.2 (Z), X1.7
ROW7: U65.2 (Z), U66.2 (Z), U67.2 (Z), U68.2 (Z), U69.2 (Z), U70.2 (Z), U71.2 (Z), U72.2 (Z), X1.8
VCC: C1.1, C2.1, C3.1, C4.1, C5.1, C6.1, C7.1, C8.1, C9.1, C10.1, C11.1, C12.1, C13.1, C14.1, C15.1, C16.1, C17.1, C18.1, C19.1, C20.1, C21.1, C22.1, C23.1, C24.1, C25.1, C26.1, C27.1, C28.1, C29.1, C30.1, C31.1, C32.1, C33.1, C34.1, C35.1, C36.1, C37.1, C38.1, C39.1, C40.1, C41.1, C42.1, C43.1, C44.1, C45.1, C46.1, C47.1, C48.1, C49.1, C50.1, C51.1, C52.1, C53.1, C54.1, C55.1, C56.1, U1.1 (VCC), U2.1 (VCC), U3.1 (VCC), U4.1 (VCC), U5.1 (VCC), U6.1 (VCC), U7.1 (VCC), U8.1 (VCC), U9.1 (VCC), U10.1 (VCC), U11.1 (VCC), U12.1 (VCC), U13.1 (VCC), U14.1 (VCC), U15.1 (VCC), U16.1 (VCC), U17.1 (VCC), U18.1 (VCC), U19.1 (VCC), U20.1 (VCC), U21.1 (VCC), U22.1 (VCC), U23.1 (VCC), U24.1 (VCC), U25.1 (VCC), U26.1 (VCC), U27.1 (VCC), U28.1 (VCC), U29.1 (VCC), U30.1 (VCC), U31.1 (VCC), U32.1 (VCC), U33.1 (VCC), U34.1 (VCC), U35.1 (VCC), U36.1 (VCC), U37.1 (VCC), U38.1 (VCC), U39.1 (VCC), U40.1 (VCC), U41.1 (VCC), U42.1 (VCC), U43.1 (VCC), U44.1 (VCC), U45.1 (VCC), U46.1 (VCC), U47.1 (VCC), U48.1 (VCC), U49.1 (VCC), U50.1 (VCC), U51.1 (VCC), U52.1 (VCC), U53.1 (VCC), U54.1 (VCC), U55.1 (VCC), U56.1 (VCC), U57.1 (VCC), U58.1 (VCC), U59.1 (VCC), U60.1 (VCC), U61.1 (VCC), U62.1 (VCC), U63.1 (VCC), U64.1 (VCC), U65.5 (VCC), U66.5 (VCC), U67.5 (VCC), U68.5 (VCC), U69.5 (VCC), U70.5 (VCC), U71.5 (VCC), U72.5 (VCC), U73.5 (VCC), U74.5 (VCC), U75.5 (VCC), U76.5 (VCC), U77.5 (VCC), U78.5 (VCC), U79.5 (VCC), U80.5 (VCC), U81.5 (VCC), U82.5 (VCC), U83.5 (VCC), U84.5 (VCC), U85.5 (VCC), U86.5 (VCC), U87.5 (VCC), U88.5 (VCC), U89.5 (VCC), U90.5 (VCC), U91.5 (VCC), U92.5 (VCC), U93.5 (VCC), U94.5 (VCC), U95.5 (VCC), U96.5 (VCC), U97.5 (VCC), U98.5 (VCC), U99.5 (VCC), U100.5 (VCC), U101.5 (VCC), U102.5 (VCC), U103.5 (VCC), U104.5 (VCC), U105.5 (VCC), U106.5 (VCC), U107.5 (VCC), U108.5 (VCC), U109.5 (VCC), U110.5 (VCC), U111.5 (VCC), U112.5 (VCC), U113.5 (VCC), U114.5 (VCC), U115.5 (VCC), U116.5 (VCC), U117.5 (VCC), U118.5 (VCC), U119.5 (VCC), U120.5 (VCC), U121.5 (VCC), U122.5 (VCC), U123.5 (VCC), U124.5 (VCC), U125.5 (VCC), U126.5 (VCC), U127.5 (VCC), U128.5 (VCC), X1.11, X1.12



Board: 4 copper layers, 54.0 x 40.0 mm, 185 parts (121 on the bottom side), 82 nets.

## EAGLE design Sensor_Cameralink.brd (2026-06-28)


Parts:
C1: 10nF 500V; C0805
D1, D2, D3, D4, D5, D6: SP3010-04UTG; UDFEN-10_MO229_LTF; LCSC C126837
GND: SJ
J1: 12226-1150-00FR; 3M_12226-1150-00FR
J2: DF17(3.0)-70DS-0.5V(57)
POCL: W237-102
R1: 1M; R0805

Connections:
+5V: J2.1, J2.2, J2.3, J2.4, J2.5, J2.6
CA_CC1+: D5.4, D5.7, J1.5, J2.54
CA_CC1-: D5.5, D5.6, J1.18, J2.56
CA_CC2+: D3.2, D3.9, J1.17, J2.55
CA_CC2-: D3.1, D3.10, J1.4, J2.53
CA_CC3+: D4.1, D4.10, J1.3, J2.60
CA_CC3-: D4.2, D4.9, J1.16, J2.62
CA_CC4+: D3.5, D3.6, J1.15, J2.61
CA_CC4-: D3.4, D3.7, J1.2, J2.59
CA_SERTC+: D5.2, D5.9, J1.20, J2.50
CA_SERTC-: D5.1, D5.10, J1.7, J2.48
CA_SERTFG+: D2.4, D2.7, J1.6, J2.47
CA_SERTFG-: D2.5, D2.6, J1.19, J2.49
CA_X0+: D1.1, D1.10, J1.12, J2.29
CA_X0-: D1.2, D1.9, J1.25, J2.31
CA_X1+: D6.1, D6.10, J1.11, J2.36
CA_X1-: D6.2, D6.9, J1.24, J2.38
CA_X2+: D1.4, D1.7, J1.10, J2.35
CA_X2-: D1.5, D1.6, J1.23, J2.37
CA_X3+: D2.1, D2.10, J1.8, J2.41
CA_X3-: D2.2, D2.9, J1.21, J2.43
CA_XCLK+: D6.4, D6.7, J1.9, J2.42
CA_XCLK-: D6.5, D6.6, J1.22, J2.44
GND: C1.2, D1.3, D1.8, D2.3, D2.8, D3.3, D3.8, D4.3, D4.8, D5.3, D5.8, D6.3, D6.8, GND.1, J1.13, J1.14, J2.7, J2.8, J2.15, J2.16, J2.21, J2.22, J2.27, J2.28, J2.33, J2.34, J2.39, J2.40, J2.45, J2.46, J2.51, J2.52, J2.57, J2.58, J2.63, J2.64, J2.69, J2.70, J2.S1 (SHIELD), J2.S2 (SHIELD), POCL.2, R1.1
unnamed: D4.4, D4.7
unnamed: D4.5, D4.6
unnamed: C1.1, J1.28 (PE2), R1.2
unnamed: GND.2, J1.1, J1.26, POCL.1



Board: 4 copper layers, 34.0 x 34.0 mm, 12 parts (7 on the bottom side), 28 nets.

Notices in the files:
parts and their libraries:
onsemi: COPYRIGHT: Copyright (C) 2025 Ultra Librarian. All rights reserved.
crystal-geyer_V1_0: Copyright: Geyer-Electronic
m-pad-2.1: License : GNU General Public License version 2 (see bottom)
